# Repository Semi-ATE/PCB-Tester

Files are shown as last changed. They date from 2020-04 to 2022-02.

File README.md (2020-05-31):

# PCB-Tester

A `PCB-Tester` is a base setup that is used to test a PCB.

The tool is used by OEM's either in new production and/or repair.

The PCB-Tester project implements such a `PCB-Tester` in open source.

It consists out of the following components:

* [Rack](https://github.com/ate-org/PCB-Tester/tree/master/hardware/mechanics/solidworks/rack) ➜ 19", holds the 'instruments' of choice when implementing a `PCB-tester` for a specific PCB.
* [Housing](https://github.com/ate-org/PCB-Tester/tree/master/hardware/mechanics/solidworks/housing) ➜ The 'box' that holds the PCB-Tester (1x [PCB-Tester-Board](https://github.com/ate-org/PCB-Tester/tree/master/hardware/electronics/altium/PCB-Tester-Board) and 0 or more [PCB-Relay-Boards](https://github.com/ate-org/PCB-Tester/tree/master/hardware/electronics/altium/PCB-Relay-Board))
* [Fixture](https://github.com/ate-org/PCB-Tester/tree/master/hardware/mechanics/solidworks/fixture) ➜ Mounted on the `Housing`, and implements the "moving parts".
* JIG ➜ **Not** a part of this project, belongs to a specific implementation. (iow: 'needle-bed')
* [The Software framework](https://github.com/ate-org/PCB-Tester/tree/master/software).

The whole thing looks like this:

<p align="center">
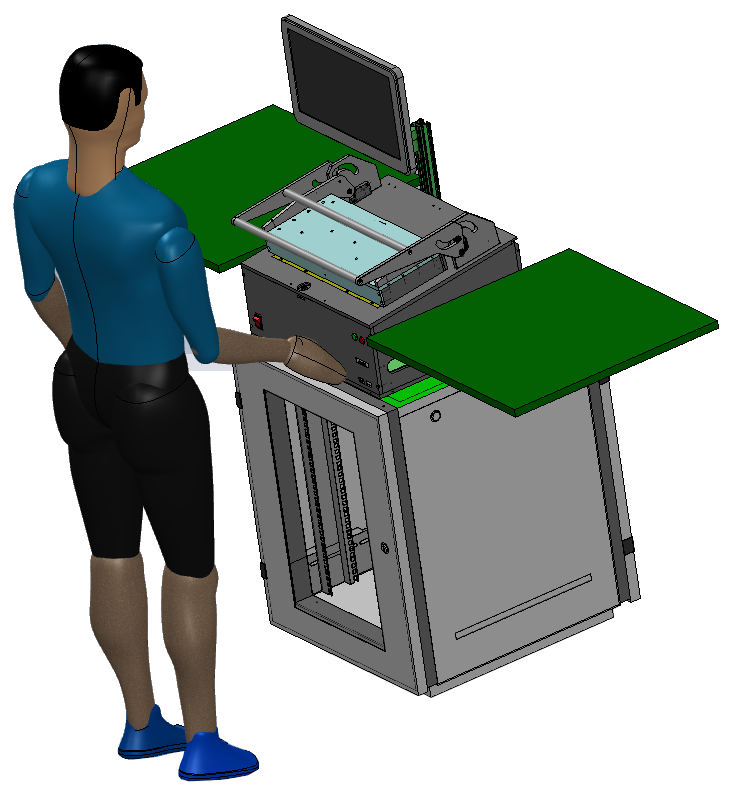
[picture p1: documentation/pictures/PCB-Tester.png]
  
</p>

# Wiki

Further reading at the project's [wiki](https://github.com/ate-org/PCB-Tester/wiki).

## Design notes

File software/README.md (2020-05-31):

# The PCB-Tester-Framework.

This directory and its subdirectories contain <ins>**any and all**</ins> sources for the `PCB-Tester-Framework`.

The `PCB-Tester-Framework` is written 100% in [Python](https://www.python.org/), and it runs on the [Raspberry Pi (4b)](https://www.raspberrypi.org/products/raspberry-pi-4-model-b/) located on the [PCB-Tester-Board](https://github.com/ate-org/PCB-Tester/tree/master/hardware/electronics/altium/PCB-Tester-Board).

A specific `PCB-Tester` <ins>implementation</ins> uses the [PCB-Tester-Template](https://github.com/ate-org/PCB-Tester-Template) repo as a starting point. The `PCB-Tester-Template` contains code, that once an implementation is finished (or later updated) it will create/update/publish a [conda](https://docs.conda.io/en/latest/) package (in the desired channel and with the desired environment) so the `PCB-Tester-Framework` can pick up on it, download it, and run it.

The `PCB-Tester-Framework` implements thus the [user interface](https://github.com/ate-org/PCB-Tester/blob/master/software/UserInterface.md), the [application interface](https://github.com/ate-org/PCB-Tester/blob/master/software/ApplicationInterface.md) ...

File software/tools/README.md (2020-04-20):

# PCB-Tester/sources/tools

Here go all the parts that have to do with the PCB-Tester as an util.

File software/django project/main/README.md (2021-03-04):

This is the viewinterface for the pcb-tester. The viewinterface is a separate module so that it is possible to change the view.

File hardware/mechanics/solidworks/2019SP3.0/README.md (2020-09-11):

# solidworks/2019SP3.0

This directory holds all the mechanical models that make up the PCB-Tester.
The assembly of the whole is to be located here.

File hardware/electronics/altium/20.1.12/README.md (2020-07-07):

# boards

| Layer | Top | Bottom |
|:---|:----|:---|
| Board Outline | Mechanical 1 | |
| Board Cutout | Mechanical 2 | |
| Electrical Bodies | Mechanical 13 | Mechanical 20 |
| Mechanical Bodies | Mechanical 14 | Mechanical 21 |
| References | Mechanical 17 | Mechanical 23 |
| Measurements | Mechanical 18 | Mechanical 22 |
| Courtyard | Mechanical 5 | Mechanical 6 |
| Designator | Mechanical 9 | Mechanical 10 |

This directory holds an entry for all the PCB's that make up the `PCB-Tester`

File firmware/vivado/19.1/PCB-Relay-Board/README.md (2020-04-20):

# PCB-Tester/vivado/PCB-Relay-Board

This directory holds the vivado project for the PCB-Relay-Board.

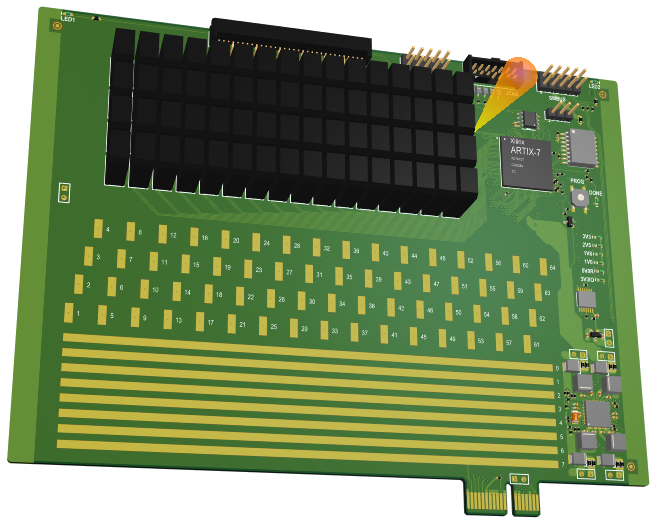
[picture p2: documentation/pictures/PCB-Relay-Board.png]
PCB-Relay-Board


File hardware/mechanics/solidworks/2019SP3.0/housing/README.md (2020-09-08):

# Housing

This is the fixed part for any PCB implementation

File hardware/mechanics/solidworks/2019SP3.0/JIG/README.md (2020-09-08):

# Fixture

This is the starting point for a PCB implementation

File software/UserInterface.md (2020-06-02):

# The PCB-Tester-Framework User Interface

The interaction with the user will be done by means of a touch-screen, as shown below.

<p align="center">
  
</p>

The monitor will be connected to the Raspberry Pi located on the []()
define here ... Django (Qt for ARMv8 probably not available 🤨)

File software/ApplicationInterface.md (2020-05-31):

# The PCB-Tester-Framework Application Interface

The `applications` are thus [conda]() packages that expose funcionality to the `PCB-Tester-Framework`.

The 'exposing' is done base on [pluggy](https://github.com/pytest-dev/pluggy).

<ins>Let it be clear</ins>, the `application` does **not** handle **any** user interaction itself! That is handled by the `PCB-Tester-Framework` on behalf of the `application`. This way, the [user interface](https://github.com/ate-org/PCB-Tester/blob/master/software/UserInterface.md) can change **without** the need to 'touch up' all previous implemented `applications`.

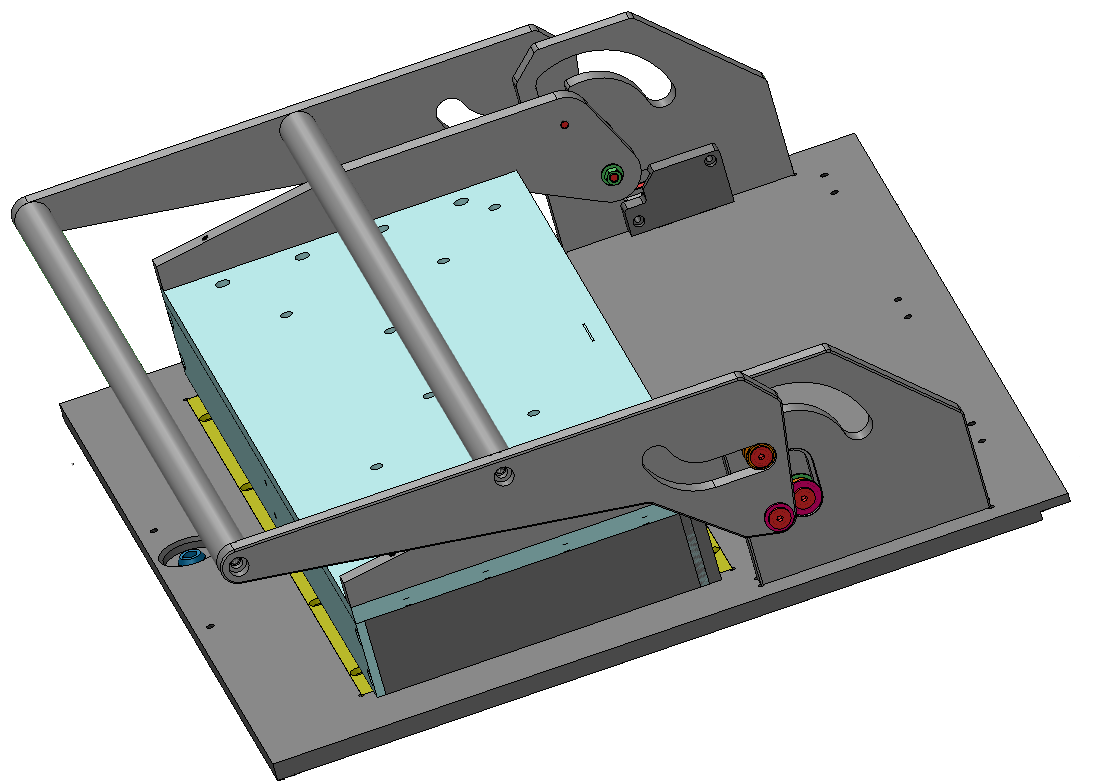
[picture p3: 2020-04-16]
documentation/pictures/fixture.png

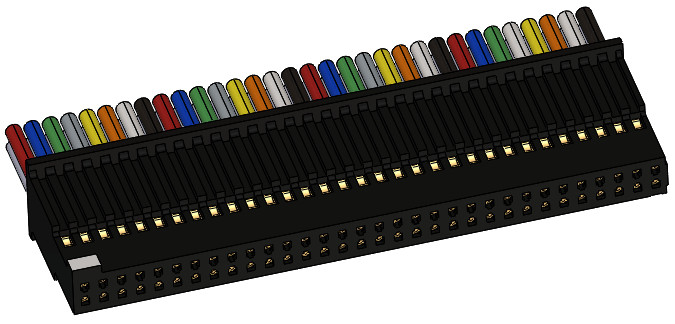
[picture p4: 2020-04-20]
documentation/pictures/SFSD-32-30C-G-15.00-S.jpg

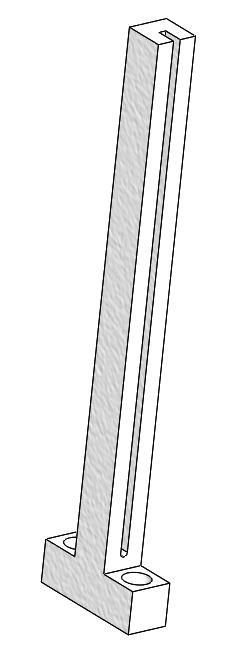
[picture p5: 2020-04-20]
documentation/pictures/SupportPost.JPG

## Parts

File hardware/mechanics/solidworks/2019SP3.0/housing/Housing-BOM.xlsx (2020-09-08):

Part | Description | Manufacturer | MPN | Supplier | SPN | Qty | Supplier Price | Total Price
Housing_bottom |  |  |  | Likom |  | 1 |  | 0
Housing_front |  |  |  | Likom |  | 1 |  | 0
Housing_back |  |  |  | Likom |  | 1 |  | 0
Housing_side |  |  |  | Likom |  | 2 |  | 0
Housing_top |  |  |  | Likom |  | 1 |  | 0
Lever_bottom_left |  |  |  | Likom |  | 1 |  | 0
Lever_bottom_right |  |  |  | Likom |  | 1 |  | 0
Lever_top_left |  |  |  | Likom |  | 1 |  | 0
Lever_top_right |  |  |  | Likom |  | 1 |  | 0
Spindlehouse_left |  |  |  | Likom |  | 1 |  | 0
Spindlehouse_right |  |  |  | Likom |  | 1 |  | 0
Handle | Handle |  |  | Likom |  | 2 |  | 0
DBGB5-20-10 | Stepped Bolt | MiSUMi | DBGB5-20-10 | MiSUMi | DBGB5-20-10 | 2 | 8.14 | 16.28
DBGB5-17-5 | Stepped Bolt | MiSUMi | DBGB5-17-5 | MiSUMi | DBGB5-17-5 | 2 | 8.14 | 16.28
DBGB5-15-10 | Stepped Bolt | MiSUMi | DBGB5-15-10 | MiSUMi | DBGB5-15-10 | 2 | 8.14 | 16.28
B688ZZ | Ball Bearing | MiSUMi | B688ZZ | MiSUMi | B688ZZ | 10 | 2.34 | 23.4
SWSJJ20-8-1 | Washer POM | MiSUMi | SWSJJ20-8-1 | MiSUMi | SWSJJ20-8-1 | 4 | 3.54 | 14.16
FWHJ-D16.0-H20.0-V8.0-T1.5-L4.0 | Washer Resin | MiSUMi | FWHJ-D16.0-H20.0-V8.0-T1.5-L4.0 | MiSUMi | FWHJ-D16.0-H20.0-V8.0-T1.5-L4.0 | 2 | 8.77 | 17.54
FWHJ-D10.5-H16.0-V8.0-T1.5-L10.0 | Washer Resin | MiSUMi | FWHJ-D10.5-H16.0-V8.0-T1.5-L10.0 | MiSUMi | FWHJ-D10.5-H16.0-V8.0-T1.5-L10.0 | 2 | 9.59 | 19.18
FRNUT5 | Flanged Nut | MiSUMi | FRNUT5 | MiSUMi | FRNUT5 | 2 | 1.75 | 3.5
420111 | Hook clamp | MiSUMi | 420111 | MiSUMi | 420111 | 2 | 2.6 | 5.2
C-30-RK-18 | Rubber Feet | MiSUMi | C-30-RK-18 | MiSUMi | C-30-RK-18 | 4 | 1.39 | 5.56
SHPSNA5 | Hinge | MiSUMi | SHPSNA5 | MiSUMi | SHPSNA5 | 3 | 6.7 | 20.1
ISO 4762 M4x12 | Socket head cap screw |  |  | Likom |  | 8 |  | 0
ISO 4762 M4x16 | Socket head cap screw |  |  | Likom |  | 24 |  | 0
ISO 4762 M2.5x12 | Socket head cap screw |  |  | Likom |  | 6 |  | 0
ISO 4762 M5x10 | Socket head cap screw |  |  | Likom |  | 6 |  | 0
ISO 4762 M5x20 | Socket head cap screw |  |  | Likom |  | 8 |  | 0
ISO 4036 M5 | Hex thin nut |  |  | Likom |  | 6 |  | 0
ISO 7045 M4x6 | Pan head cross recess screw |  |  | Likom |  | 4 |  | 0
ISO 1207 M4x8 | Slotted cheese head screw |  |  | Likom |  | 6 |  | 0
ISO 8734 1x8 | Dowel |  |  | Likom |  | 4 |  | 0
 |  |  |  |  |  |  |  | 157.48

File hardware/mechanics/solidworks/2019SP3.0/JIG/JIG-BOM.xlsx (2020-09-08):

Part | Description | Manufacturer | MPN | Supplier | SPN | Qty | Supplier Price | Total Price
Cover_top | Cover top plate |  |  | Likom |  | 1 |  | 0
Cover_short | Cover left/right plates |  |  | Likom |  | 2 |  | 0
Cover_long | Cover front/rear plates |  |  | Likom |  | 2 |  | 0
Needlebed | Needlebed plate |  |  | Likom |  | 1 |  | 0
ISO 7046 M3x10 | Countersunk flat head cross recess screw |  |  | Likom |  | 6 |  | 0
ISO 4762 M4x16 | Socket head cap screw |  |  | Likon |  | 22 |  | 0
ISO 4762 M3x16 | Socket head cap screw |  |  | Likom |  | 2 |  | 0
JBH6-10 | bushing for locating pin | MiSUMi | JBH6-10 | MiSUMi | JBH6-10 | 2 | 7.4 | 14.8
SFTF6-55-J5-M3 | Locating pin | MiSUMi | SFTF6-55-J5-M3 | MiSUMi | SFTF6-55-J5-M3 | 2 | 13.2 | 26.4
 |  |  |  |  |  |  |  | 41.2

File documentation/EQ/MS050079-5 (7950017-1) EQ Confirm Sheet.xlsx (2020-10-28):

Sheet: EQ
瀚宇博德股份有限公司
Hannstar Board Corporation
工程問題確認單
Engineering Questions Confirm
客戶料號(Customer P/N)： |  | MS050079-5 | 日期(Date)： |  | 2020-10-23
廠內料號(HSB P/N)： |  | 7950017-1 | 製作者(Prepared by)： |  | Vincent Liu
項次 Item | 問題內容與建議 Description and Recommendation |  | 附件 Attachment | 客戶回覆 Customer Response |  | 客戶簽名 Signature & Date
Q1 | Please confirm the panelization. |  | #1 | Likom OK |  | TDK OK
Q2 | Please confirm our recommended stackup. No require impedance so we don't control its. |  | #2 |  |  | TDK OK
Q3 | We suggest adding Dummy PAD at break-away in outer layer for plating better, please confirm. |  | #3 | Likom OK |  | TDK OK
Q4 | Please confirm beveling spec. |  | #4 |  |  | TDK OK
Q5 | We will add UL MARK, DC in silkscreen layer in top side, please confirm. |  |  | Likom OK |  | TDK OK
Q6 | Soldermask color is green, Silkscreen color is white, please confirm. |  |  |  |  | TDK OK
Q7 | Surface finish is ENIG and gold thickness is 2μ", please confirm. |  |  |  |  | TDK OK
Q8 | Plating gold finger thickness is 10μ", please confirm. |  |  |  |  | TDK OK
Q9 | We will not ask again for above Eqs for future revision. Please approve. |  |  |  |  | TDK OK
Q10
1.請勿修改問題與建議欄位。
Please don't modify Description and Recommendation column.
2.請於客戶回覆欄位填入回覆意見，如有附件請新增頁面。
Please enter your comment into Customer Response column, and add new sheet if any attachment.
3.回覆後請於客戶簽名欄位填入確認者及日期。
Please sign your name and date after replied.
保存期限:壹年以上 |  |  |  |  |  | S103-3-001-01A

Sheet: #1
Panel Size:6.496"*5.709" PCS Size:6.496"*5.079" (Ignore "A", they aren't match actual size)
Break-away width:8mm and 17mm
1.V-CUT number total is 3
2.CNC routing width is 3mm
3.V-CUT jump spacing is 20mm
4.We will add "PCB-Tester Relay Board for U33111" in break-away.
5.Adding tooling and fiducial mark as below:
 | Top Side: | Round fiducial mark with Dummy dots in square shape
 | Bottom Side: | Square fiducial mark with Dummy dots in round shape

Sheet: #2
Total thickness: 61.53mil
Outer layer is 0.5oz+plating, finish copper is more than 1oz.

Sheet: #3
TOP
BOT

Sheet: #4
Angle：20°
Depth：55mil

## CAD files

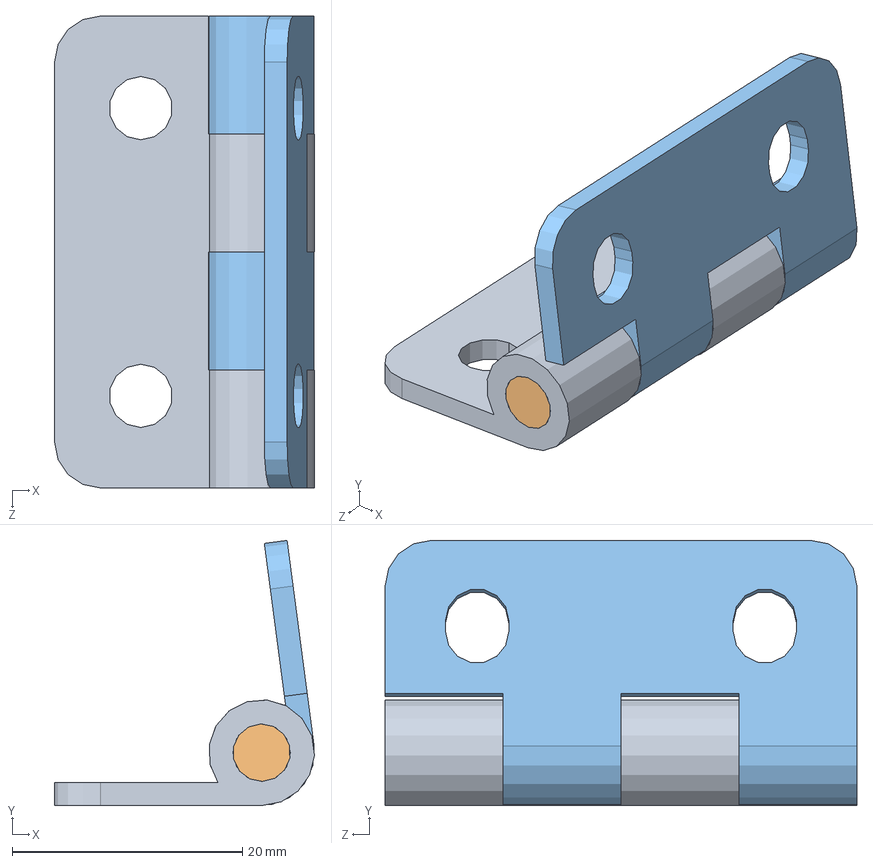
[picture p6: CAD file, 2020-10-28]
hardware/mechanics/solidworks/2019SP3.0/housing/SHPSNA5.sldasm
22.6 x 23.0 x 41.0 mm
SHPSNA5_3
SHPSNA5_7
SHPSNA5_5

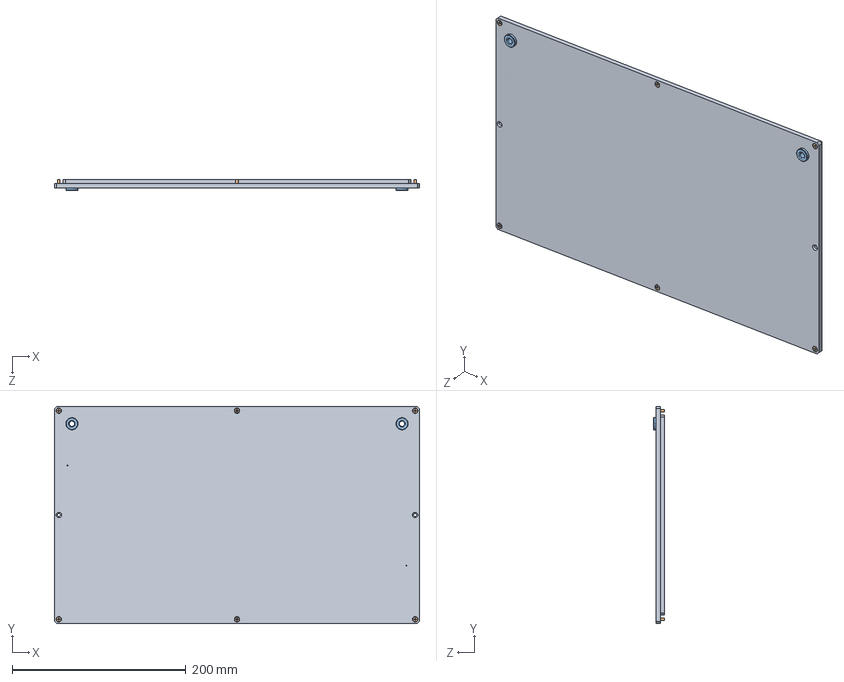
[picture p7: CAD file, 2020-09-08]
hardware/mechanics/solidworks/2019SP3.0/JIG/Needlebed.SLDASM
420.0 x 250.0 x 13.0 mm
Needlebed
countersunk flat head cross recess screw_iso x 6
JBH6_10 x 2

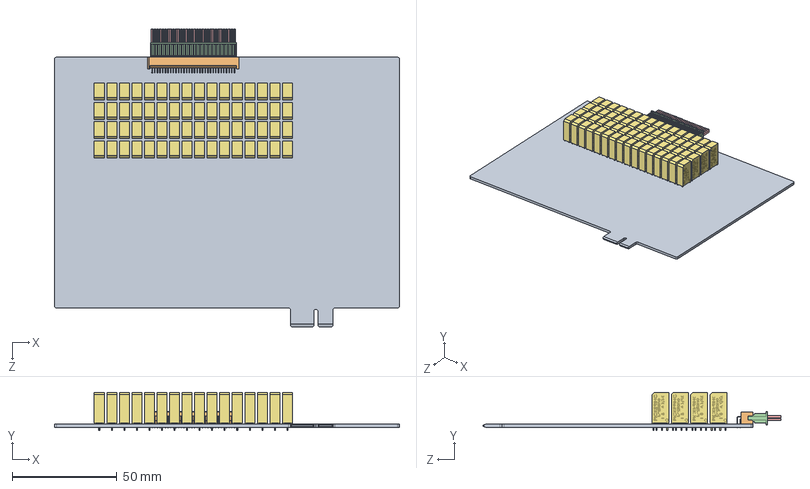
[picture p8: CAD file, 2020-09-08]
hardware/mechanics/solidworks/2019SP3.0/PCB-Relay-Board/PCB-Relay-Board.SLDASM
165.0 x 18.4 x 142.4 mm
PCB-Relay-PCB
_TFC_132_01_L_D_RA_terminal_2
_TFC_132_01_L_D_RA_pins_4
_SFSD_32_30_S_b_2
_SFSD_32_28_D_NUS_ca_4
_SFSD_32_p_6 x 2
118-1-A x 64

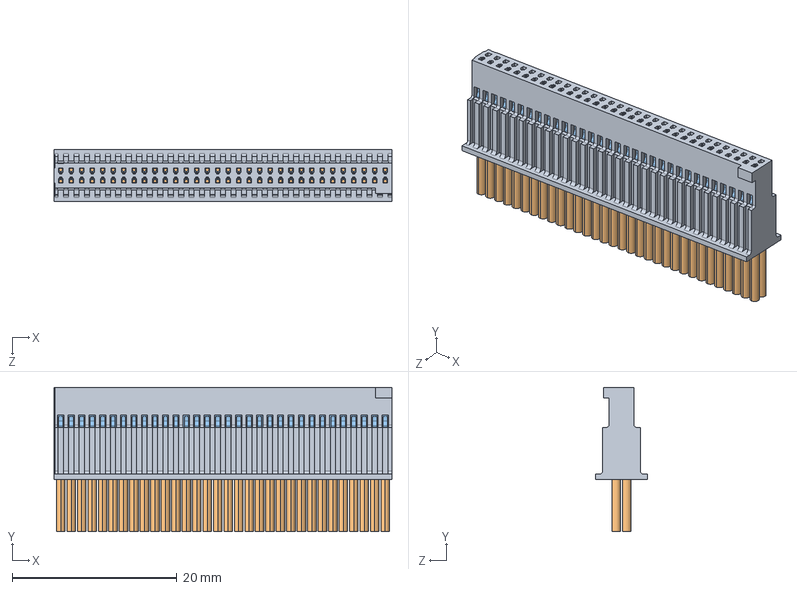
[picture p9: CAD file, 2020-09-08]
hardware/mechanics/solidworks/2019SP3.0/PCB-Relay-Board/SFSD-32-30C-G-15.00-S/SFSD_32_30C_G_15_00_S.sldasm
41.0 x 17.5 x 6.35 mm
_SFSD_32_30_S_b_2
_SFSD_32_28_D_NUS_ca_4
_SFSD_32_p_6 x 2

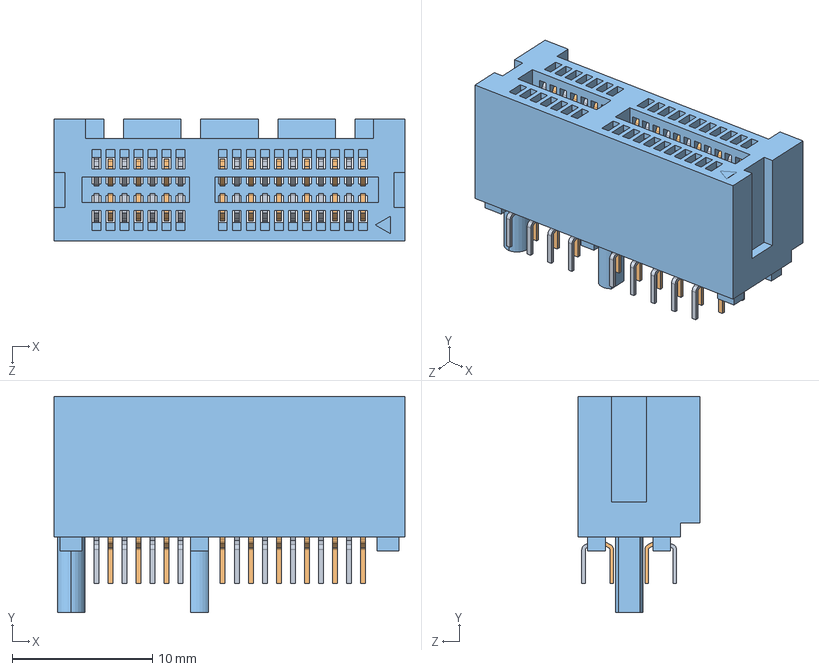
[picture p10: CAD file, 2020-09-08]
hardware/mechanics/solidworks/2019SP3.0/PCB-Tester-Board/PCIE-036-02-F-D-TH/PCIE_036_02_F_D_TH.sldasm
25.0 x 15.4 x 8.70 mm
PCIE_036_02_F_D_TH_3
PCIE_036_02_F_D_TH_5
PCIE_036_02_F_D_TH_7

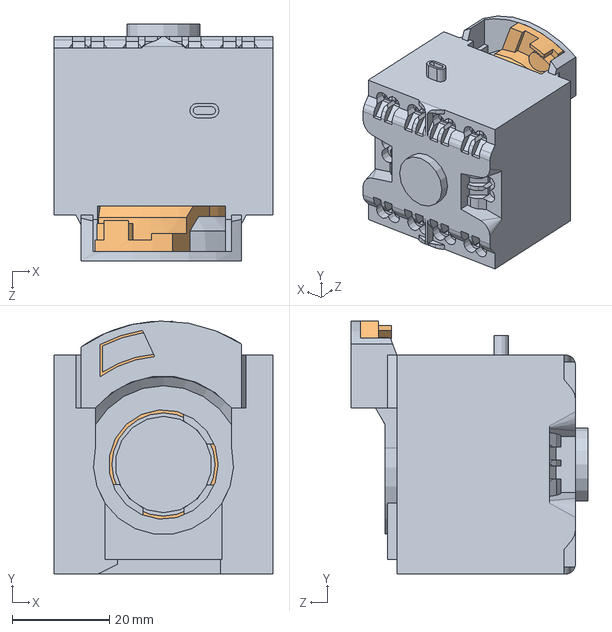
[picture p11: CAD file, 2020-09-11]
hardware/mechanics/solidworks/2019SP3.0/housing/A22NE-M-PD22-N/A22NE_M_PD22_N_TERMINAL.SLDASM
45.0 x 52.0 x 48.7 mm
A22NE_M_PD22_N_TERMINAL
A22NE_M_PD22_N_LEVER

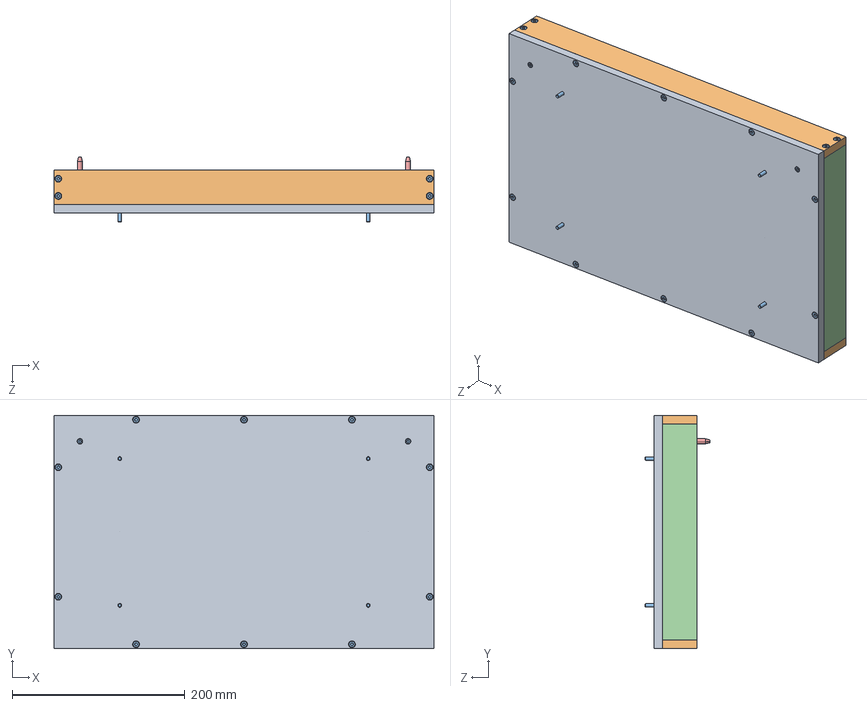
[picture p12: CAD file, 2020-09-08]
hardware/mechanics/solidworks/2019SP3.0/JIG/Cover.SLDASM
440.0 x 270.0 x 75.0 mm
Cover_top
Cover_long x 2
socket head cap screw_iso x 24
Cover_short x 2
SFTF6_55_J5_M3 x 2

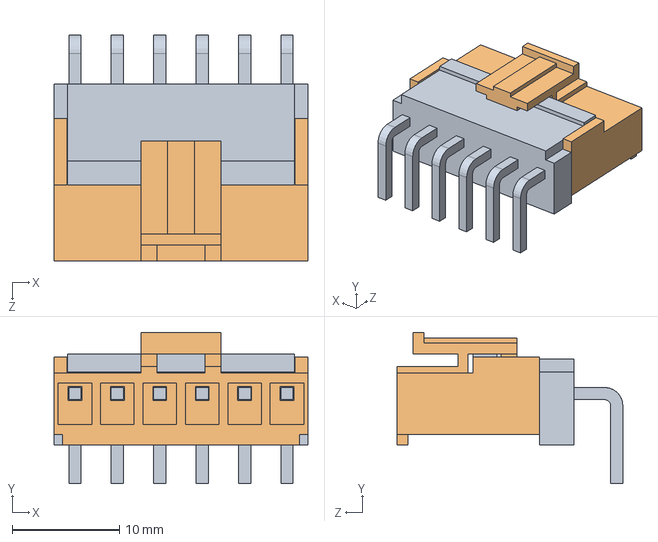
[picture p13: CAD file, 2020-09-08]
hardware/mechanics/solidworks/2019SP3.0/PCB-Tester-Board/B6PS-VH/B6PS-VH.SLDASM
23.7 x 14.1 x 21.1 mm
B6PS-VH
VHR-6N

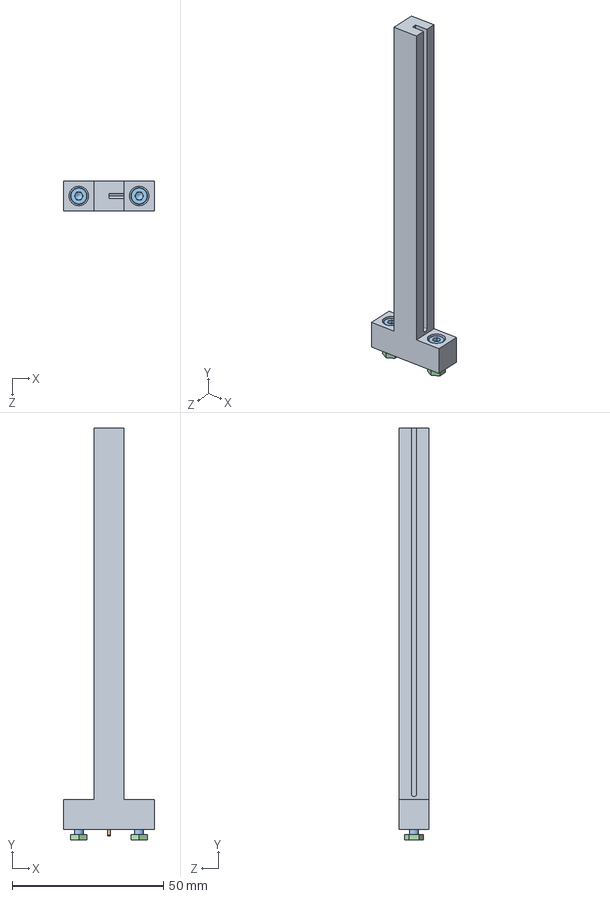
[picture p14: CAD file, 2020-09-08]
hardware/mechanics/solidworks/2019SP3.0/PCB-Tester-Board/SupportPost.SLDASM
30.0 x 136.4 x 10.0 mm
SupportPost
parallel pin hardened_iso
socket head cap screw_iso x 2
hex thin nut gradeb_iso x 2

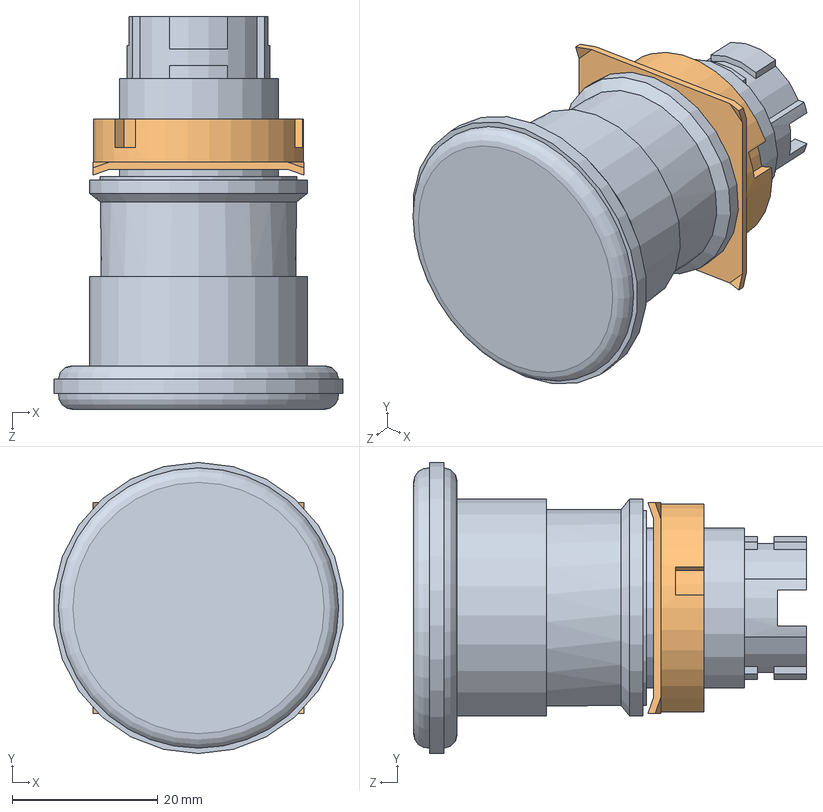
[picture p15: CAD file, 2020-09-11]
hardware/mechanics/solidworks/2019SP3.0/housing/A22NE-M-PD22-N/A22NE_M_N.SLDASM
39.7 x 40.0 x 54.0 mm
A22NE_M_N_BASE
A22NE_M_N_NUT

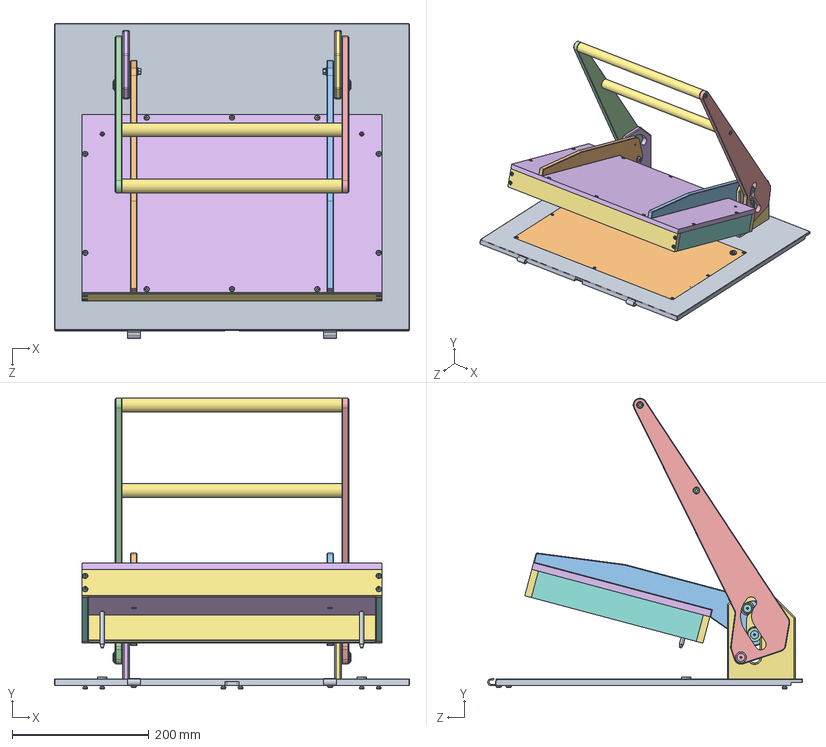
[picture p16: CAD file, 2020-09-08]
hardware/mechanics/solidworks/2019SP3.0/JIG/Fitting.SLDASM
520.0 x 425.7 x 461.0 mm
Housing_top
Lever_bottom_left
Lever_bottom_right
Lever_top_left
Lever_top_right
Spindlehouse_left
Spindlehouse_right
DBGB5-20-10 x 2
B688ZZ x 10
SWSJJ20-8-1 x 6
DBGB5-15-10 x 2
FWHJ-D16.0-H20.0-V8.0-T1.5-L4.0 x 2
DBGB5-17-5 x 2
FWHJ-D10.5-H16.0-V8.0-T1.5-L10.0 x 2
Handle x 2
FRNUT5 x 2
420111_hook x 2
pan head cross recess screw_iso x 4
slotted cheese head screw_iso x 6
socket head cap screw_iso x 32
parallel pin hardened_iso x 4
Cover_top
Cover_long x 2
Cover_short x 2
SFTF6_55_J5_M3 x 2
Needlebed
countersunk flat head cross recess screw_iso x 6
JBH6_10 x 2

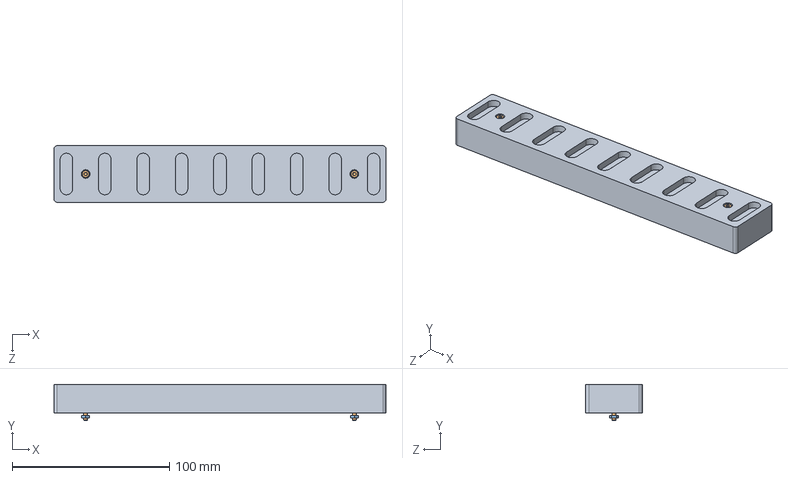
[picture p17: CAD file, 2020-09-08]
hardware/mechanics/solidworks/2019SP3.0/PCB-Tester-Board/SupportBlock.SLDASM
211.0 x 22.9 x 36.0 mm
SupportBlock
socket head cap screw_iso x 2
hex thin nut gradeb_iso x 2

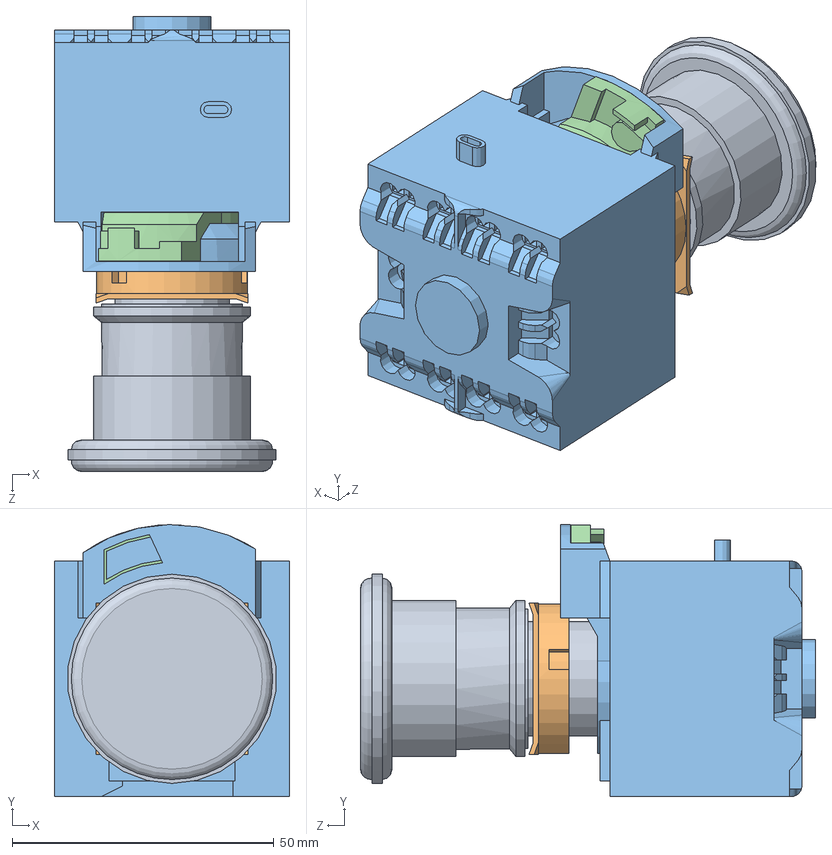
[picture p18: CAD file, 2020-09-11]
hardware/mechanics/solidworks/2019SP3.0/housing/A22NE-M-PD22-N/A22NE_M_PD22_N.SLDASM
45.0 x 52.0 x 87.0 mm
A22NE_M_N_BASE
A22NE_M_N_NUT
A22NE_M_PD22_N_TERMINAL
A22NE_M_PD22_N_LEVER

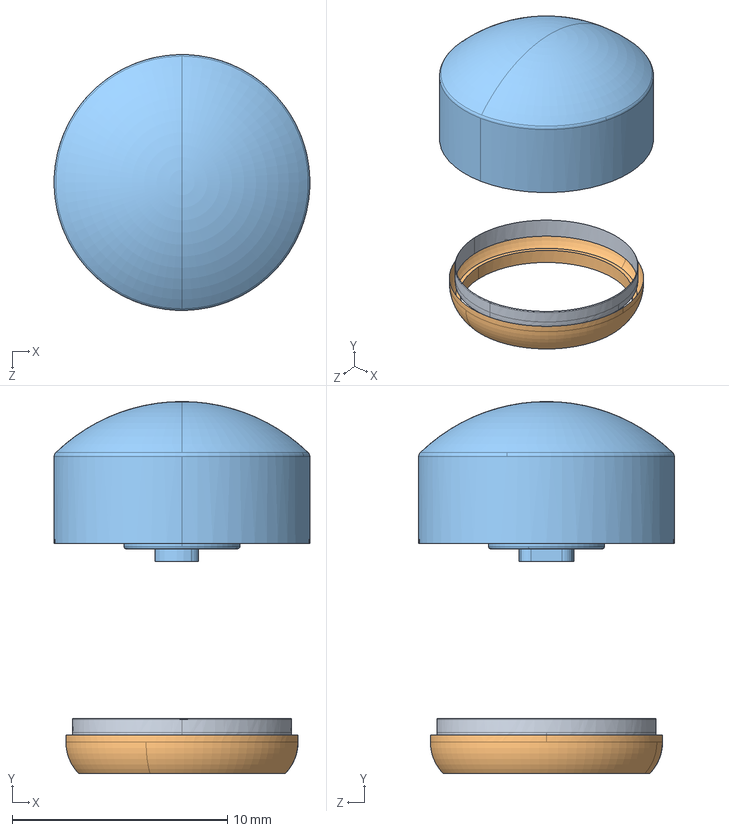
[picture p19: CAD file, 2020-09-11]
hardware/mechanics/solidworks/2019SP3.0/housing/NP8E2D203QE/NP8E2D203QE.sldasm
11.9 x 17.3 x 11.9 mm
NP8E2D203QE_3
NP8E2D203QE_11
NP8E2D203QE_13

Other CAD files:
hardware/mechanics/solidworks/2019SP3.0/PCB-Tester-Board/Raspberry Pi 4B/RPI4B.SLDASM
hardware/mechanics/solidworks/2019SP3.0/housing/Lever_top.SLDASM
hardware/mechanics/solidworks/2019SP3.0/housing/Housing.SLDASM
hardware/mechanics/solidworks/2019SP3.0/housing/Spindle3.SLDASM
hardware/electronics/altium/20.1.12/PCB-Tester-Board/PCB-Tester-Board.DXF
hardware/electronics/altium/20.1.12/PCB-Tester-Board/Parts/SupportBlock.STEP
hardware/electronics/altium/20.1.12/PCB-Tester-Board/Parts/SupportPost.STEP
hardware/electronics/altium/20.1.12/PCB-Tester-Relay-Board/Board-Outline.DXF
hardware/mechanics/solidworks/2019SP3.0/HUMAN BODY.SLDPRT
hardware/mechanics/solidworks/2019SP3.0/JIG/Cover_long.SLDPRT
hardware/mechanics/solidworks/2019SP3.0/JIG/Cover_short.SLDPRT
hardware/mechanics/solidworks/2019SP3.0/JIG/Cover_top.SLDPRT
hardware/mechanics/solidworks/2019SP3.0/JIG/JBH6_10.sldprt
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

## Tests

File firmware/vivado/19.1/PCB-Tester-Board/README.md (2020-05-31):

# Firmware for the PCB-Tester-Board.

This directory holds the vivado project for the `PCB-Tester-Board`.

<p align="center">
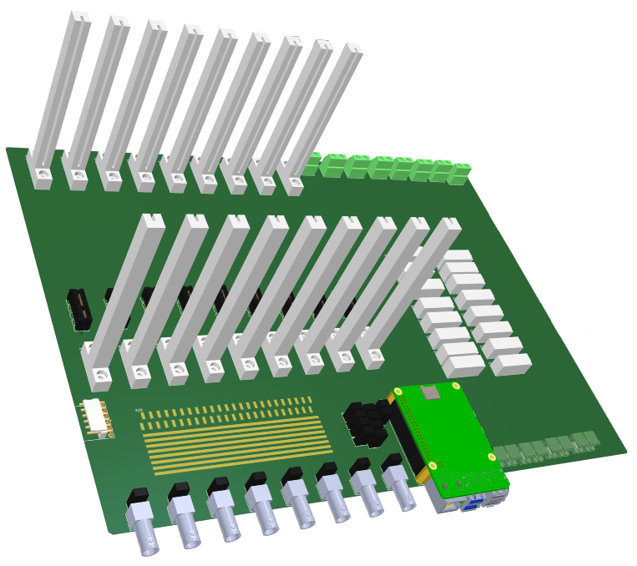
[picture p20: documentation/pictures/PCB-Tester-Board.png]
  
</p>

The implemented functionality:
  - Relay driver :
  - ...

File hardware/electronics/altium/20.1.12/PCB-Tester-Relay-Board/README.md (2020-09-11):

# PCB-Relay-Board

The PCB-Relay-Board is basically a 64:8 relay matrix extension for the PCB-Tester.

 PCB-Relay-Board

It consists out of 2 parts :
- altium : the hardware design (schematics, libraries & layout)
- [vivado](/firmware/vivado/19.1/PCB-Relay-Board/) : the implementation of the FPGA

#TODO:
- [X] enlarge the number of relays from 48 to 64
- [X] add an extra pin to the header(s) for SDA (The FTDI-Cables need 2 contacts for the SDA)
- [X] add a header to the SPI interfaces (both on X7A15T-Fabric.schdoc)
- [X] change J3 to a pull-down and a 2 pin header for writing, (but don't put the header itself), remove the jumper X35 from the schematics.
- [X] change J4 to a pull-down and a 2 pin header for writing, (but don't put the header itself),remove the jumper X37 from the schematics.
- [X] put some text on the LED's (top overlay) indicating the voltage level.

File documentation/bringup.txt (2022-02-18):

Bringup procedure for PCB-Tester-Board

0. Disconnect the 24V PSU (on the wall) from the PCB and remove the PCB from the housing.
1. Check if 24V from the PSU is provided with correct polarity (both plugs should be wired the same way).
2. Connect 230VAC to the power inlet and check if the PSU produces correctly 24V DC. If nothing happens, check the fuses in the drawer in the inlet.
On the PCB:
3. Check if there are no short-circuits at testpoints. Remove Raspberry Pi. Connect 24V DC to X2. Check if the board produces correctly 12V rail (TP5) and 5V rails (TP10, TP13).
4. Remove power, short jumper J15 (use tin or populate 0R) and place Raspberry Pi back in its socket.
5. Apply power, program IRPS5401. Use the config file from directory "firmware/PowIRCenter/Build <number>/PCB-Tester-Board" (currently, <number> is 7369).
6. Re-power the board. Check if IRPS5401 produces correctly the voltage rails: 1V (TP6), 1.8V (TP7), and 3.3V (TP9).
7. Remove power, short jumpers J5, J6, J9, J10, J11, J12 (use tin or populate 0R).
8. Apply power, program the configuration flash of the FPGA using the file from directory "firmware/vivado/<version>/PCB-Tester-Board" (currently <version> is 19.1).
9. Cycle power, check if the FPGA boots up (lits LED "DONE").

Bringup procedure for PCB-Relay-Board

0. Check if there are no short-circuits at testpoints and that (if populated) TVSes D7, D8, D9, D10, D11 are not pulling the voltage rail and the signals to GND. Prepare working PCB-Tester-Board. Position the PCB-Relay-Board in a free slot allowing access to the board.
1. Apply power, check if the 12V rail is ok (TP6), check the 5V rail (TP5) and the 3.3V rail (TP7).
2. Program IRPS5401. Use the config file from directory "firmware/PowIRCenter/Build <number>/PCB-Relay-Board" (currently, <number> is 7369).
3. Cycle power, check if the voltage rails are produced correctly: 1V (TP1), 1.8V (TP2), and 3.3V (TP4).
4. Remove power, remove the board from the slot. Short jumpers J1, J2, J4, J5, J8, J9 (use tin or populate 0R).
5. Position the board in the slot, apply power. Program the configuration flash of the FPGA using the file from directory "firmware/vivado/<version>/PCB-Relay-Board" (currently <version> is 19.1).
6. Cycle power, check if the FPGA boots up (lits LED "DONE").

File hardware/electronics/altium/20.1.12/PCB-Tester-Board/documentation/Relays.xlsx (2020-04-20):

DRV | Scematic | Relay
1 | ADC | K2 | ABUS0 to ADC
2 | ADC | K3 | ABUS1 to ADC
3 | ADC | K4 | ABUS2 to ADC
4 | ADC | K5 | ABUS3 to ADC
5 | ADC | K6 | ABUS4 to ADC
6 | ADC | K7 | ABUS5 to ADC
7 | ADC | K8 | ABUS6 to ADC
8 | ADC | K9 | ABUS7 to ADC
9 | ADC | K10 | ADC range
10 | ADC | K11 | ADC range
11 | Controller |  | OUT1
12 | Controller |  | OUT2
13 | Controller |  | OUT3
14 | Controller |  | OUT4
15 | Controller |  | OUT5
16 | Top |  | Connect Instrument 1 to ABUS0
17 | Top |  | Connect Instrument 2 to ABUS1
18 | Top |  | Connect Instrument 3 to ABUS2
19 | Top |  | Connect Instrument 4 to ABUS3
20 | Top |  | Connect Instrument 5 to ABUS4
21 | Top |  | Connect Instrument 6 to ABUS5
22 | Top |  | Connect Instrument 7 to ABUS6
23 | Top |  | Connect Instrument 8 to ABUS7
24 | PowerRouting | K12 | X4-X5
25 | PowerRouting | K13
26 | PowerRouting | K14 | X7-X8
27 | PowerRouting | K15
28 | PowerRouting | K15 | X10-X11
29 | PowerRouting | K17
30 | PowerRouting | K18 | X15-X14
31 | PowerRouting | K19
32 | PowerRouting | K20 | X17-X18
33 | PowerRouting | K21
34 | PowerRouting | K22 | X21-X20
35 | PowerRouting | K23
36 | PowerRouting | K24 | X25-X23
37 | PowerRouting | K25
38 | PowerRouting | K26 | X27-X26
39 | PowerRouting | K27
40-103 | SignalRouting | K28-K91

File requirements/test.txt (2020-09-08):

mock
pytest
pytest-cov
pytest-mock
coverage
check-manifest
pre-commit

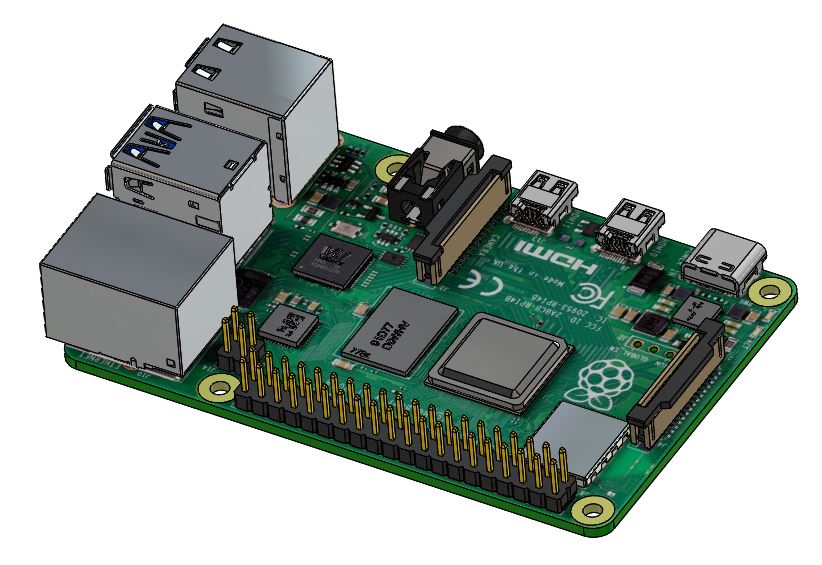
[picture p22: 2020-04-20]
hardware/mechanics/solidworks/2019SP3.0/PCB-Tester-Board/Raspberry Pi 4B/RPI4B.JPG

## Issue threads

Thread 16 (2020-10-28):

Missing gerber layer

nerohmot, 2020-10-28:
fix the missing gerber and upload to Likom
while at it, also make the output folder like other projects.

nerohmot, 2020-10-28:
also make a new release

nerohmot, 2020-10-28:
done, sent to Likom

Closed 2020-10-28.

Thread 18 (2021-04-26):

capacitors on 5V0R

A-R-f, 2021-04-26:
Both boards have no decoupling capacitors on 5V0R rail near the relays. Something might be added in the next revision.

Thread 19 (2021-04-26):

SD card is missing in BOM of the Tester Board

A-R-f, 2021-04-26:

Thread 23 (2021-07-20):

TVSes near JTAG connector on Relay Board are rotated 180 degrees

A-R-f, 2021-07-20:
Because of symbol-footprint mismatch, the design of the Relay Board comprises the TVSes D7, D8, D9, D10, D11 (5 pcs. in total) with incorrect orientation (the cathode goes where the anode should go).

This should be corrected in the next revision.

On the existing board, the easiest fix is to not populate them.
Other possible fix is to rotate them to correct orientation, but then the EMS should be aware of this and not rotate them back.

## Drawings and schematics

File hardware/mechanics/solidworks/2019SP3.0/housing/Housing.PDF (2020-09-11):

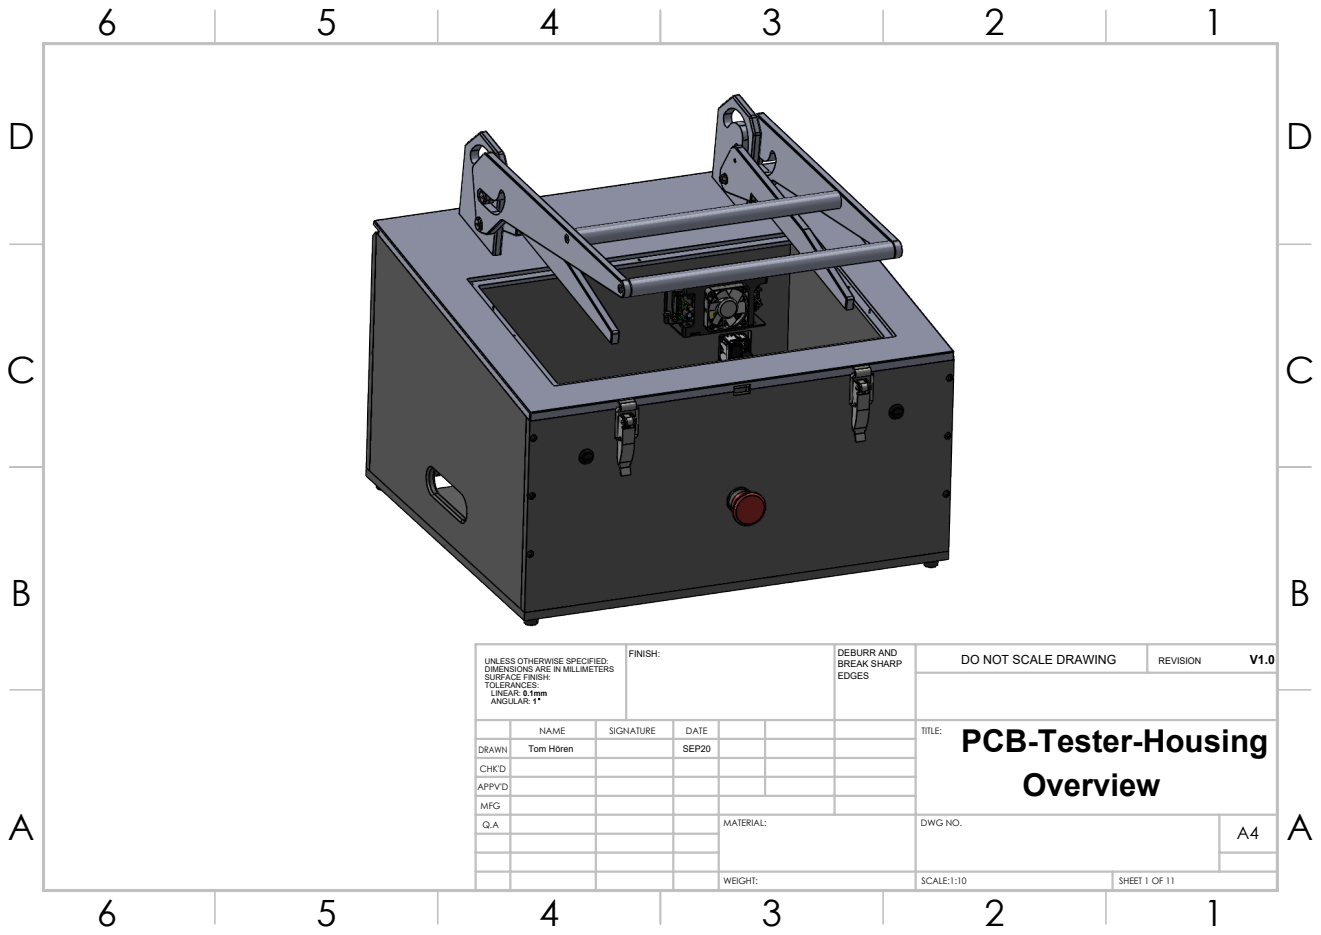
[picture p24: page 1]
FINISH:; DEBURR AND; BREAK SHARP; DO NOT SCALE DRAWING; REVISION; SCALE:1:10; SHEET 1 OF 11

UNLESS OTHERWISE SPECIFIED:
DIMENSIONS ARE IN MILLIMETERS
SURFACE FINISH:
TOLERANCES:
LINEAR: 0.1mm
ANGULAR: 1

NAME | SIGNATURE | DATE | | | | PCB-Tester-Housing TITLE: Overview

DRAWN | Tom Hören | | SEP20
CHK'D
APPV'D
MFG
Q.A | | | | MATERIAL: | DWG NO. | A4

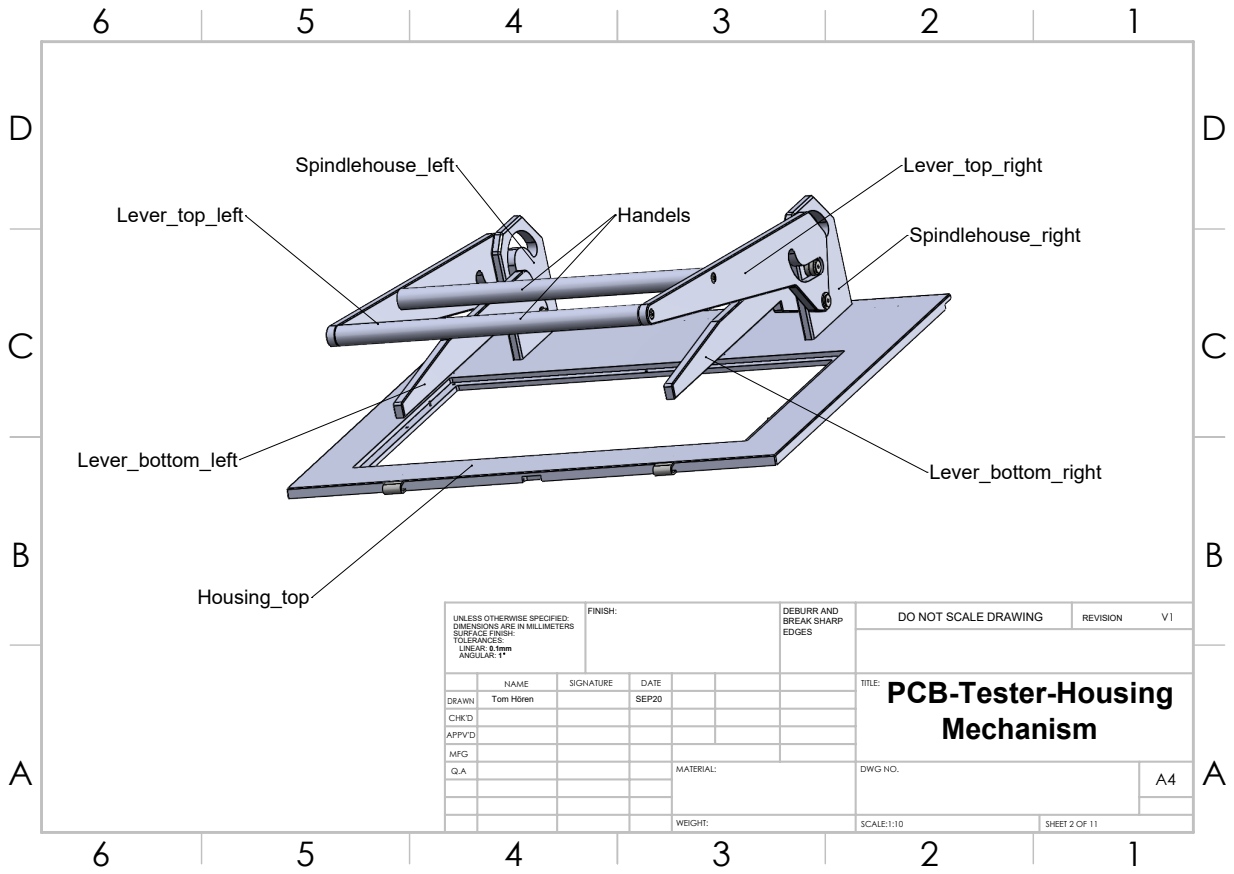
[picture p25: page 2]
Lever_bottom_right Lever_bottom_left; FINISH:; DEBURR AND; BREAK SHARP; DO NOT SCALE DRAWING; REVISION; SCALE:1:10; SHEET 2 OF 11

UNLESS OTHERWISE SPECIFIED:
DIMENSIONS ARE IN MILLIMETERS
SURFACE FINISH:
TOLERANCES:
LINEAR: 0.1mm
ANGULAR: 1

NAME | SIGNATURE | DATE | | | | PCB-Tester-Housing TITLE: Mechanism

DRAWN | Tom Hören | | SEP20
CHK'D
APPV'D
MFG
Q.A | | | | MATERIAL: | DWG NO. | A4

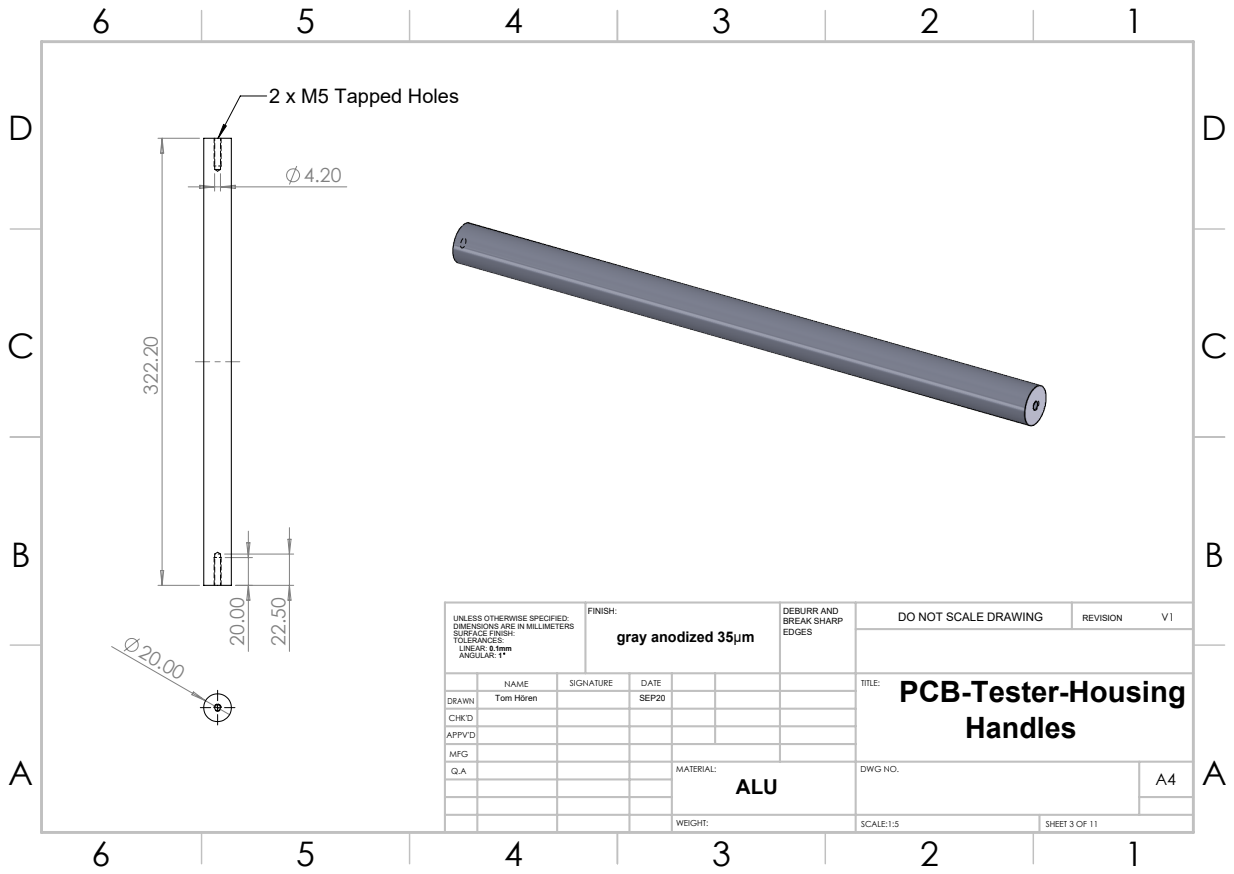
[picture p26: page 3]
2 x M5 Tapped Holes; FINISH:; DEBURR AND; BREAK SHARP; DO NOT SCALE DRAWING; REVISION; SCALE:1:5; SHEET 3 OF 11; gray anodized 35μm

UNLESS OTHERWISE SPECIFIED:
DIMENSIONS ARE IN MILLIMETERS
SURFACE FINISH:
TOLERANCES:
LINEAR: 0.1mm
ANGULAR: 1

NAME | SIGNATURE | DATE | | | | PCB-Tester-Housing TITLE: Handles

DRAWN | Tom Hören | | SEP20

CHK'D
APPV'D
MFG
Q.A | | | | MATERIAL: ALU | DWG NO. | A4

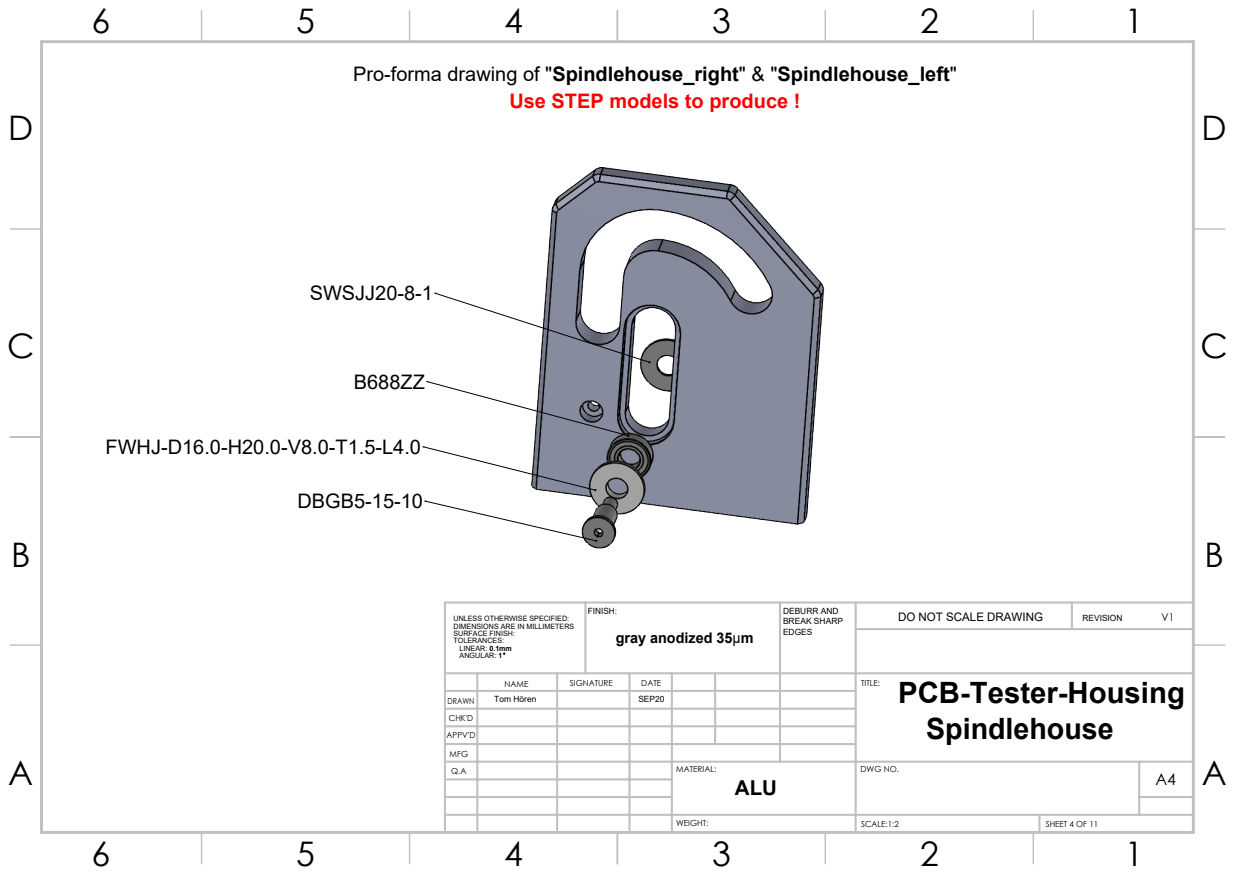
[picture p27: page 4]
FINISH:; DEBURR AND; BREAK SHARP; DO NOT SCALE DRAWING; REVISION; SCALE:1:2; SHEET 4 OF 11; gray anodized 35μm

Pro-forma drawing of "Spindlehouse_right" & "Spindlehouse_left"

Use STEP models to produce !

UNLESS OTHERWISE SPECIFIED:
DIMENSIONS ARE IN MILLIMETERS
SURFACE FINISH:
TOLERANCES:
LINEAR: 0.1mm
ANGULAR: 1

Tom Hören NAME | SIGNATURE | SEP20 DATE | | | | PCB-Tester-Housing TITLE: Spindlehouse

DRAWN
CHK'D
APPV'D
MFG
Q.A | | | | MATERIAL: ALU | DWG NO. | A4

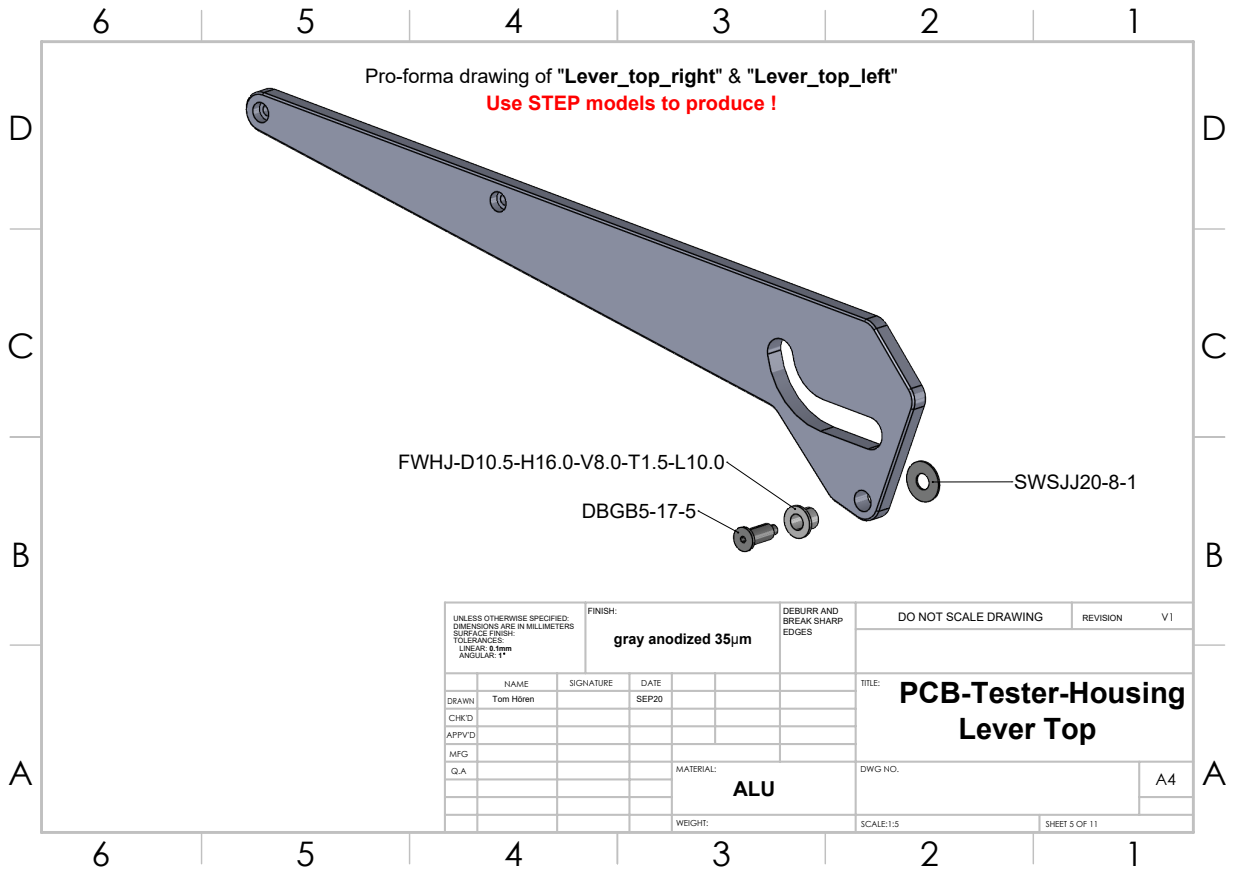
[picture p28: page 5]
FINISH:; DEBURR AND; BREAK SHARP; DO NOT SCALE DRAWING; REVISION; gray anodized 35μm

Pro-forma drawing of "Lever_top_right" & "Lever_top_left"

Use STEP models to produce !

UNLESS OTHERWISE SPECIFIED:
DIMENSIONS ARE IN MILLIMETERS
SURFACE FINISH:
TOLERANCES:
LINEAR: 0.1mm
ANGULAR: 1

Tom Hören NAME | SIGNATURE | SEP20 DATE | | | | PCB-Tester-Housing TITLE: Lever Top

DRAWN
CHK'D
APPV'D
MFG
Q.A | | | | MATERIAL: ALU | DWG NO. | A4

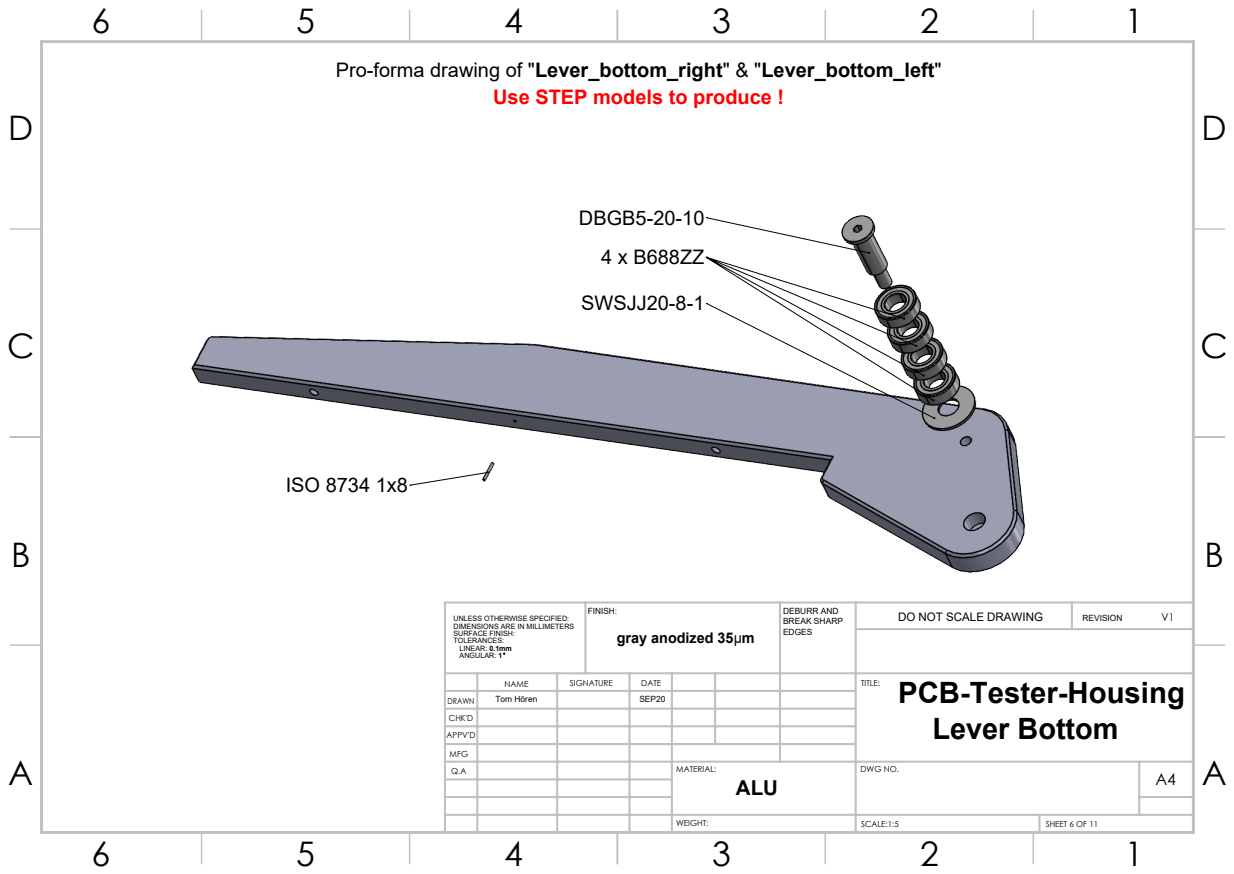
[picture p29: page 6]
ISO 8734 1x8; FINISH:; DEBURR AND; BREAK SHARP; DO NOT SCALE DRAWING; REVISION; gray anodized 35μm

Pro-forma drawing of "Lever_bottom_right" & "Lever_bottom_left"

Use STEP models to produce !

UNLESS OTHERWISE SPECIFIED:
DIMENSIONS ARE IN MILLIMETERS
SURFACE FINISH:
TOLERANCES:
LINEAR: 0.1mm
ANGULAR: 1

Tom Hören NAME | SIGNATURE | SEP20 DATE | | | | PCB-Tester-Housing TITLE: Lever Bottom

DRAWN
CHK'D
APPV'D
MFG
Q.A | | | | MATERIAL: ALU | DWG NO. | A4

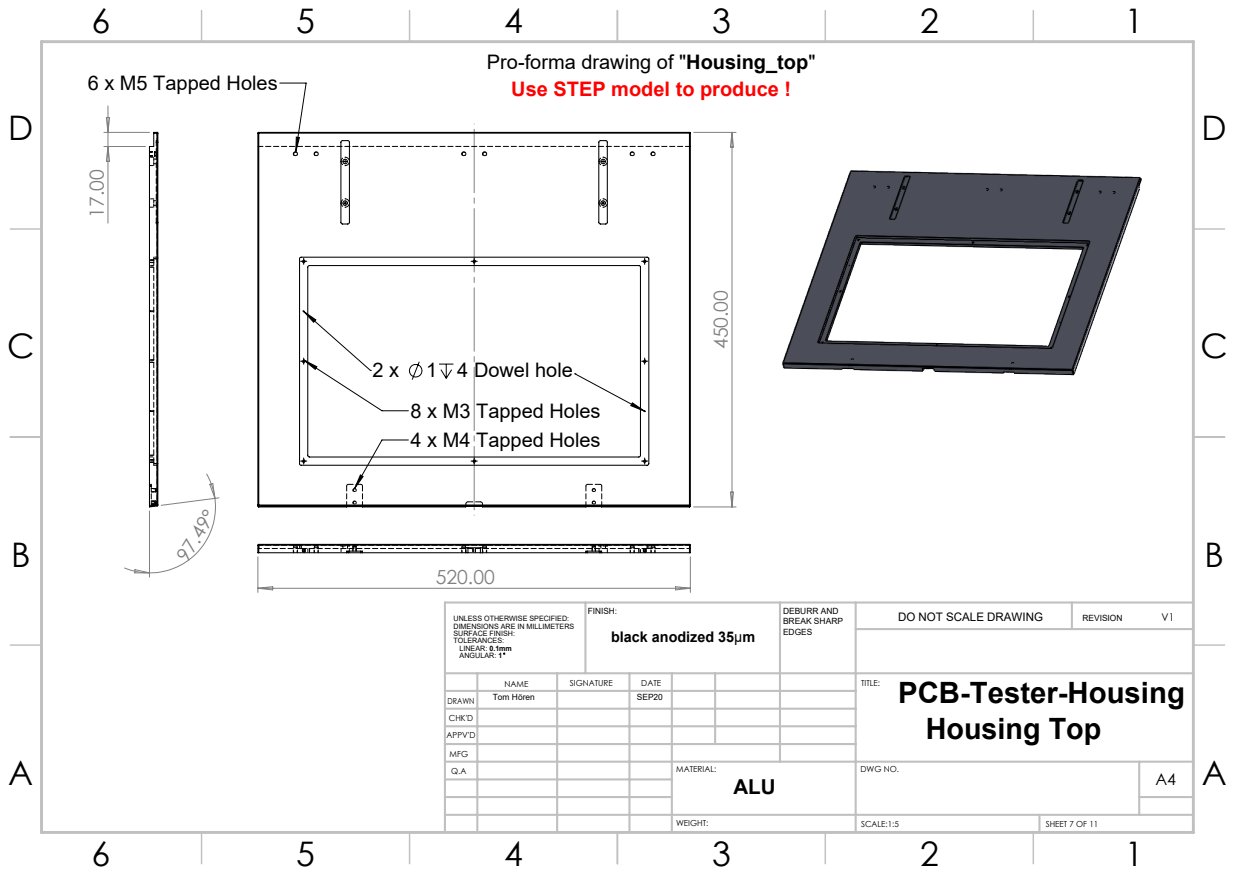
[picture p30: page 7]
8 x M3 Tapped Holes 4 x M4 Tapped Holes; 2 x 1 4 Dowel hole; 6 x M5 Tapped Holes 17.00; FINISH:; DEBURR AND; BREAK SHARP; DO NOT SCALE DRAWING; REVISION; black anodized 35μm

Pro-forma drawing of "Housing_top"
Use STEP model to produce !

UNLESS OTHERWISE SPECIFIED:
DIMENSIONS ARE IN MILLIMETERS
SURFACE FINISH:
TOLERANCES:
LINEAR: 0.1mm
ANGULAR: 1

Tom Hören NAME | SIGNATURE | SEP20 DATE | | | | PCB-Tester-Housing TITLE: Housing Top

DRAWN
CHK'D
APPV'D
MFG
Q.A | | | | MATERIAL: ALU | DWG NO. | A4

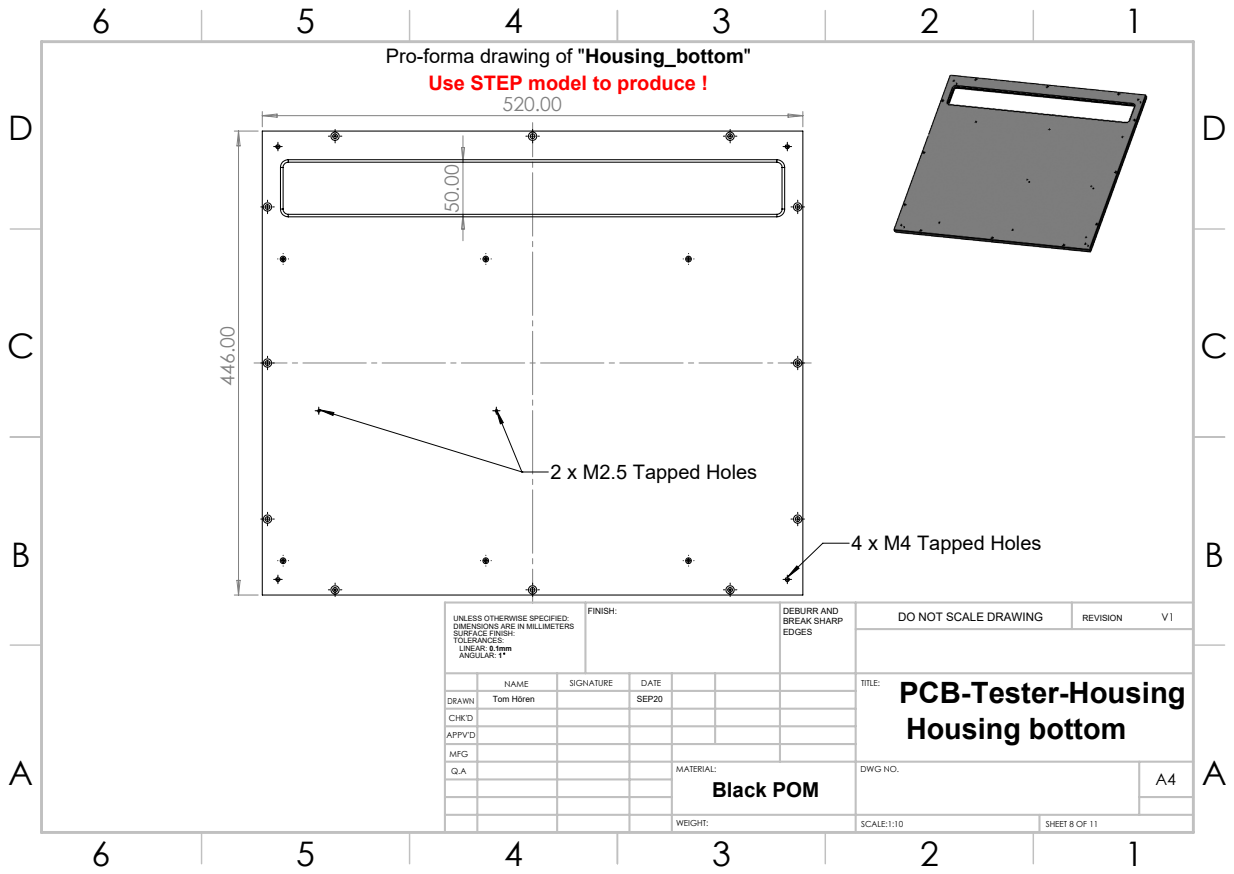
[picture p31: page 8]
4 x M4 Tapped Holes; 2 x M2.5 Tapped Holes; FINISH:; DEBURR AND; BREAK SHARP; DO NOT SCALE DRAWING; REVISION; SCALE:1:10; SHEET 8 OF 11

Pro-forma drawing of "Housing_bottom"
Use STEP model to produce !

UNLESS OTHERWISE SPECIFIED:
DIMENSIONS ARE IN MILLIMETERS
SURFACE FINISH:
TOLERANCES:
LINEAR: 0.1mm
ANGULAR: 1

Tom Hören NAME | SIGNATURE | SEP20 DATE | | | | PCB-Tester-Housing TITLE: Housing bottom

DRAWN
CHK'D
APPV'D
MFG
Q.A | | | | MATERIAL: Black POM | DWG NO. | A4

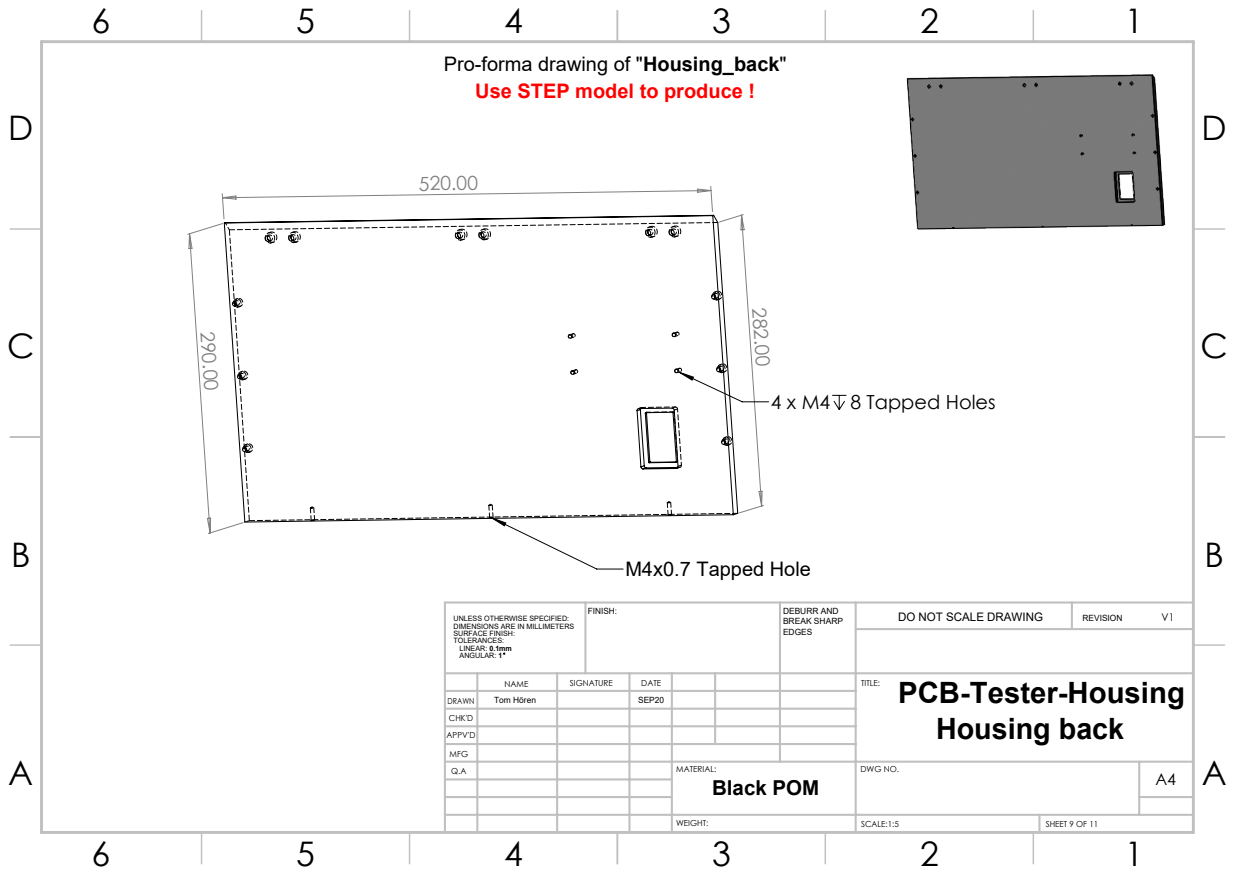
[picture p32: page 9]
M4x0.7 Tapped Hole; 4 x M4 8 Tapped Holes; FINISH:; DEBURR AND; BREAK SHARP; DO NOT SCALE DRAWING; REVISION

Pro-forma drawing of "Housing_back"
Use STEP model to produce !

UNLESS OTHERWISE SPECIFIED:
DIMENSIONS ARE IN MILLIMETERS
SURFACE FINISH:
TOLERANCES:
LINEAR: 0.1mm
ANGULAR: 1

Tom Hören NAME | SIGNATURE | SEP20 DATE | | | | PCB-Tester-Housing TITLE: Housing back

DRAWN
CHK'D
APPV'D
MFG
Q.A | | | | MATERIAL: Black POM | DWG NO. | A4

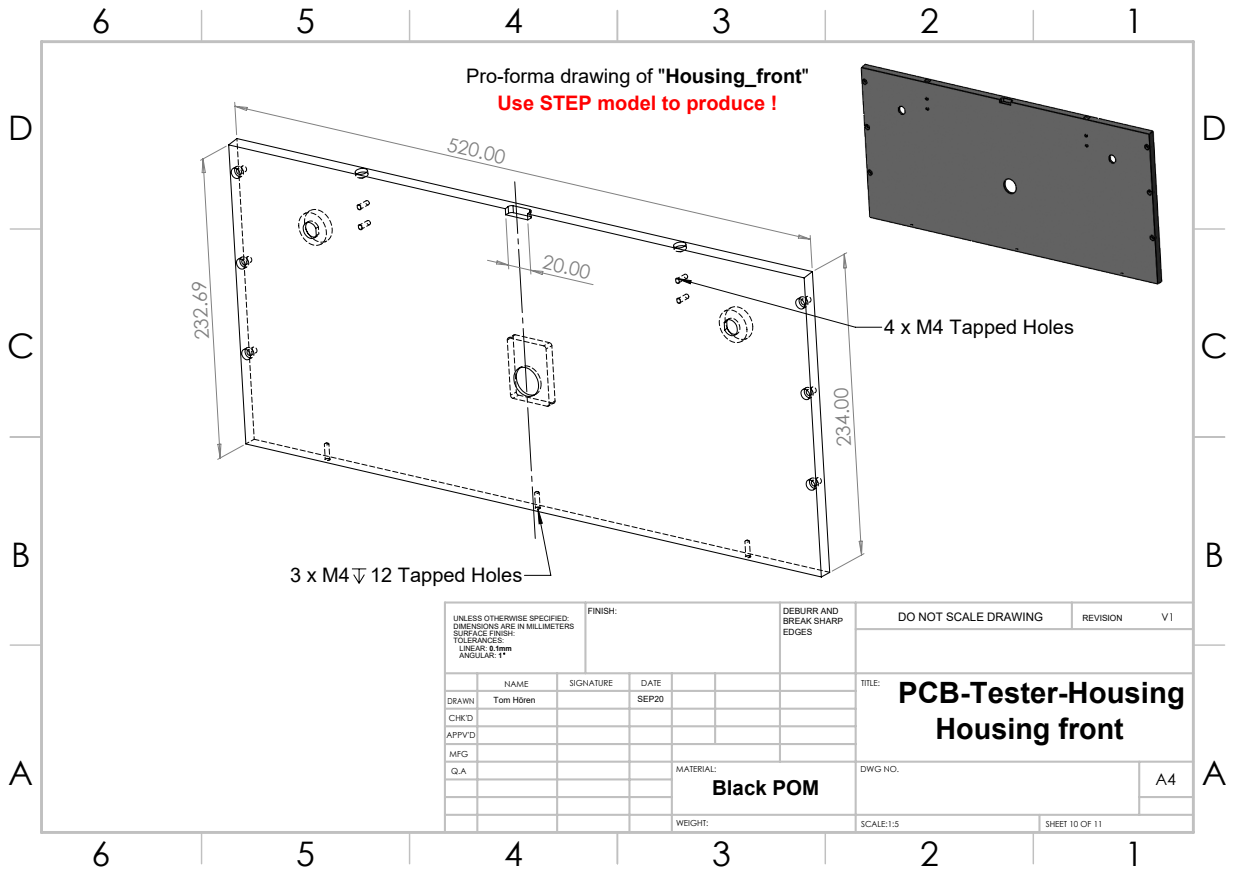
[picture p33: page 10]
4 x M4 Tapped Holes; 3 x M4 12 Tapped Holes; FINISH:; DEBURR AND; BREAK SHARP; DO NOT SCALE DRAWING; REVISION

Pro-forma drawing of "Housing_front"
Use STEP model to produce !

UNLESS OTHERWISE SPECIFIED:
DIMENSIONS ARE IN MILLIMETERS
SURFACE FINISH:
TOLERANCES:
LINEAR: 0.1mm
ANGULAR: 1
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

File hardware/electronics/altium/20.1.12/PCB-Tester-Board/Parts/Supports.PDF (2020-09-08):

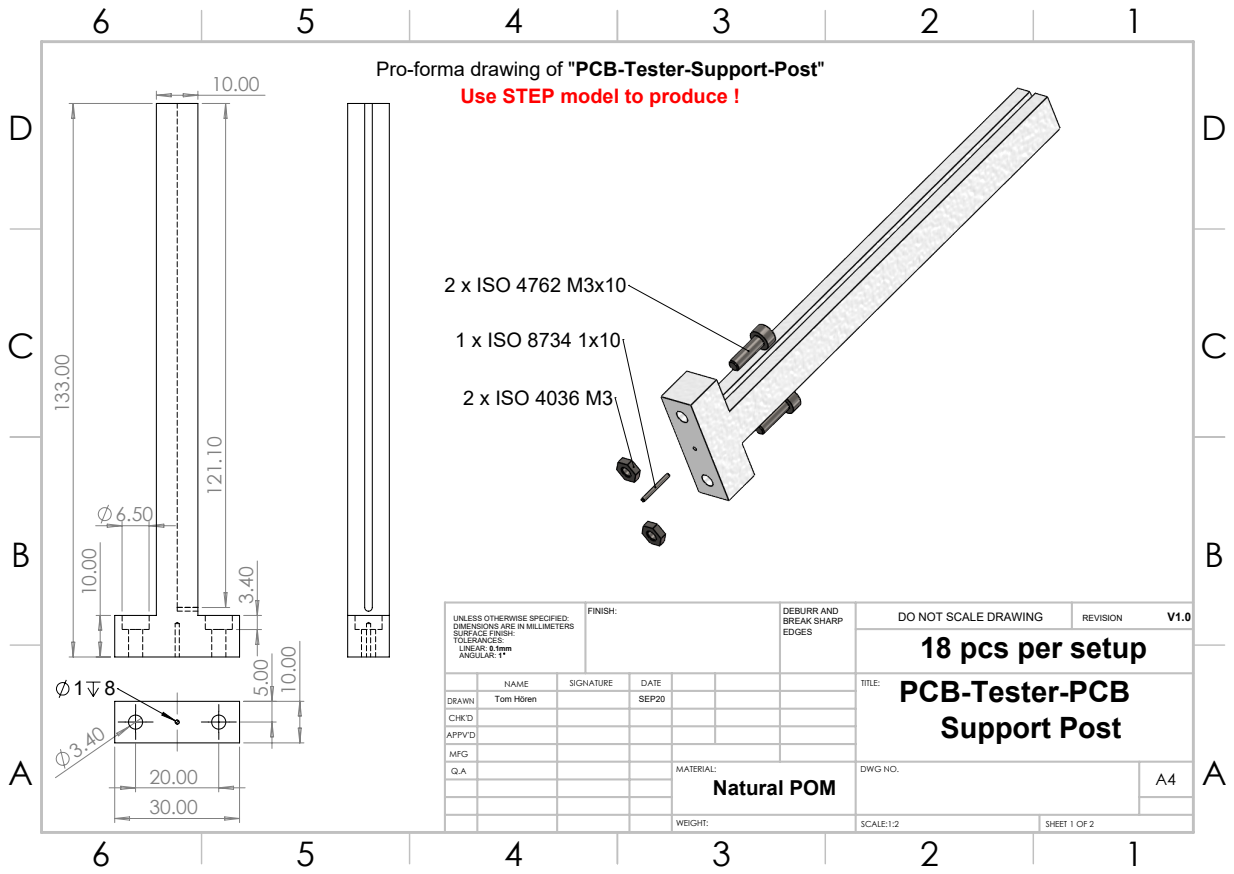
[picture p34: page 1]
2 x ISO 4762 M3x10; 2 x ISO 4036 M3; 1 x ISO 8734 1x10; FINISH:; DEBURR AND; BREAK SHARP; DO NOT SCALE DRAWING; REVISION; SCALE:1:2; SHEET 1 OF 2

Pro-forma drawing of "PCB-Tester-Support-Post"
Use STEP model to produce !

UNLESS OTHERWISE SPECIFIED:
DIMENSIONS ARE IN MILLIMETERS
SURFACE FINISH:
TOLERANCES:
LINEAR: 0.1mm
ANGULAR: 1

18 pcs per setup

NAME | SIGNATURE | DATE | | | | PCB-Tester-PCB TITLE: Support Post

DRAWN | Tom Hören | | SEP20
CHK'D
APPV'D
MFG
Q.A | | | | MATERIAL: Natural POM | DWG NO. | A4

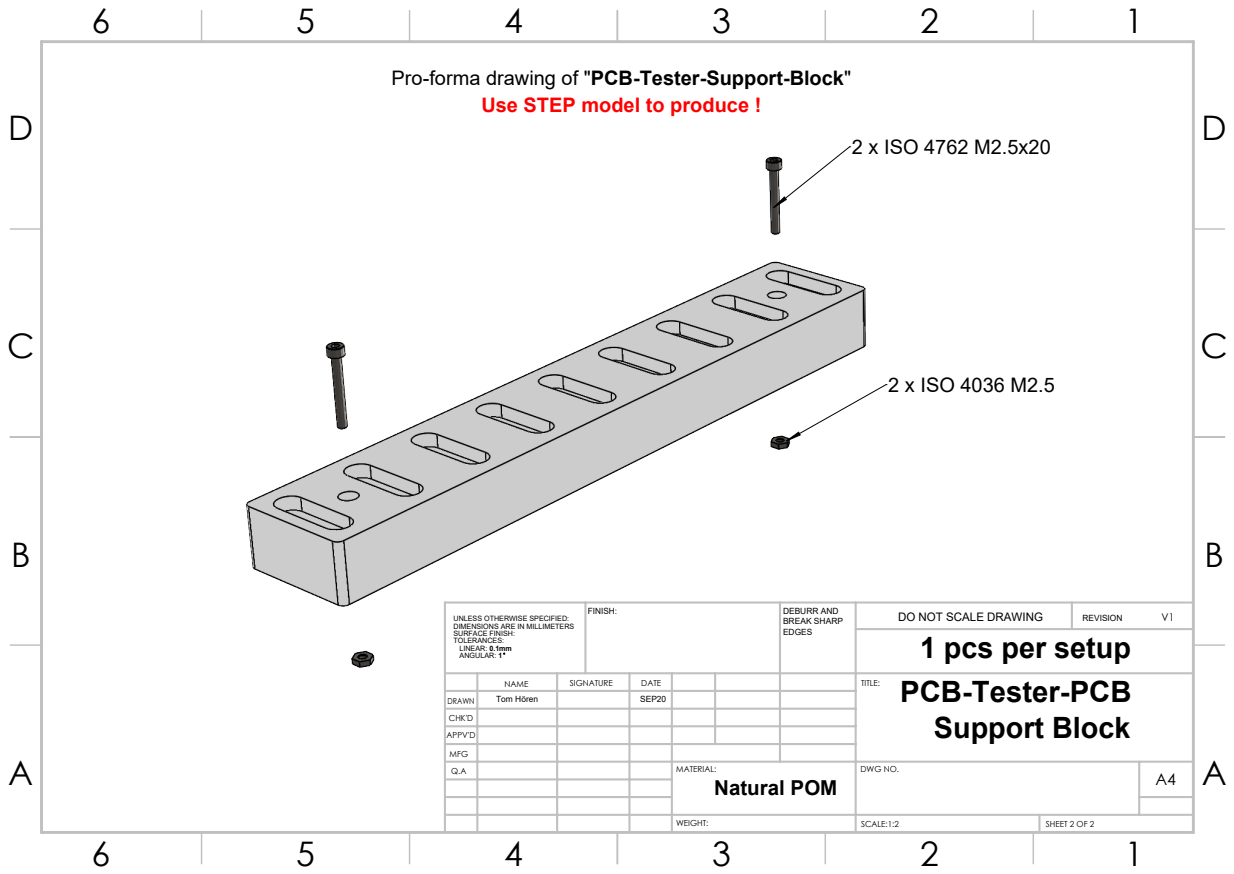
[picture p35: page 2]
2 x ISO 4762 M2.5x20; 2 x ISO 4036 M2.5; FINISH:; DEBURR AND; BREAK SHARP; DO NOT SCALE DRAWING; REVISION; SCALE:1:2; SHEET 2 OF 2

Pro-forma drawing of "PCB-Tester-Support-Block"

Use STEP model to produce !

UNLESS OTHERWISE SPECIFIED:
DIMENSIONS ARE IN MILLIMETERS
SURFACE FINISH:
TOLERANCES:
LINEAR: 0.1mm
ANGULAR: 1

1 pcs per setup

NAME | SIGNATURE | DATE | | | | PCB-Tester-PCB TITLE: Support Block

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

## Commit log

2020-07-09 PCB-Tester BOM cleaned up except of "PCB Tester Support"
    [ADC.SchDoc, Controller.SchDoc, Input.SchDoc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]
2020-07-09 BOMs cleaned up (excl. "PCB Tester Support")
    [PCB-Relay-Board-V1.SchDoc, PCB-Tester-Board-V1.PrjPcb, PSU1.SchDoc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]
2020-07-22 small design review changes
    [AC-Cable.SchDoc, ADC.SchDoc, Controller.SchDoc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]
2020-08-04 signals added to FPGA: power-on-reset, and reset from RPi, and function selection FUN
    [Controller.SchDoc, PCB-Relay-Board-V1.PrjPcb, PCB-Relay-Board-V1.SchDoc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]
2020-09-08 added mechanical stuff
    [112778.SLDPRT, 112778.step, 118-1-A.SLDPRT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]
2020-09-11 make release V1.0
    [A22NE_M_N.SLDASM, A22NE_M_N_BASE.SLDPRT, A22NE_M_N_NUT.SLDPRT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]
2021-04-26 config files for the PMICs on PCB-Tester-Board and PCB-Relay-Board, created with IR PowIRCenter
